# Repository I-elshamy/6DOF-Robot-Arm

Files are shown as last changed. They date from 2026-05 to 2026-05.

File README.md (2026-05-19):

# 🤖 Industrial Robotics Project

Welcome to our Industrial Robotics project repository!  
This project was developed as part of the Industrial Robotics course submission and focuses on building, controlling, and simulating a robotic arm system using modern robotics tools and embedded systems.

---

<table>
<tr>
<td>

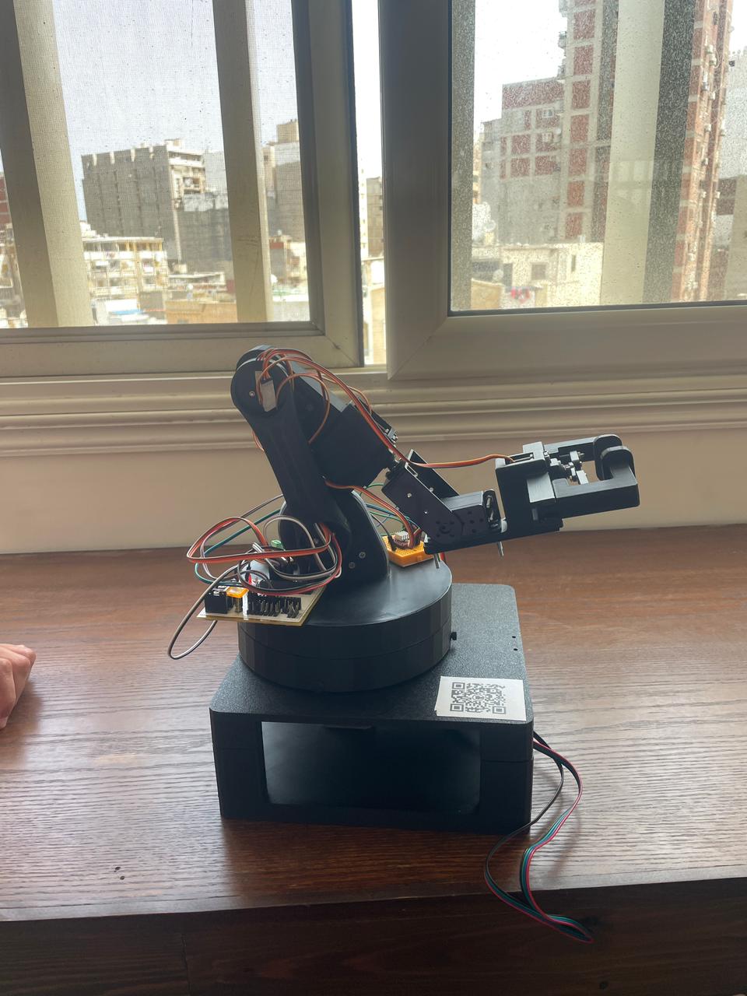
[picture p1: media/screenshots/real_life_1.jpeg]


</td>
<td>

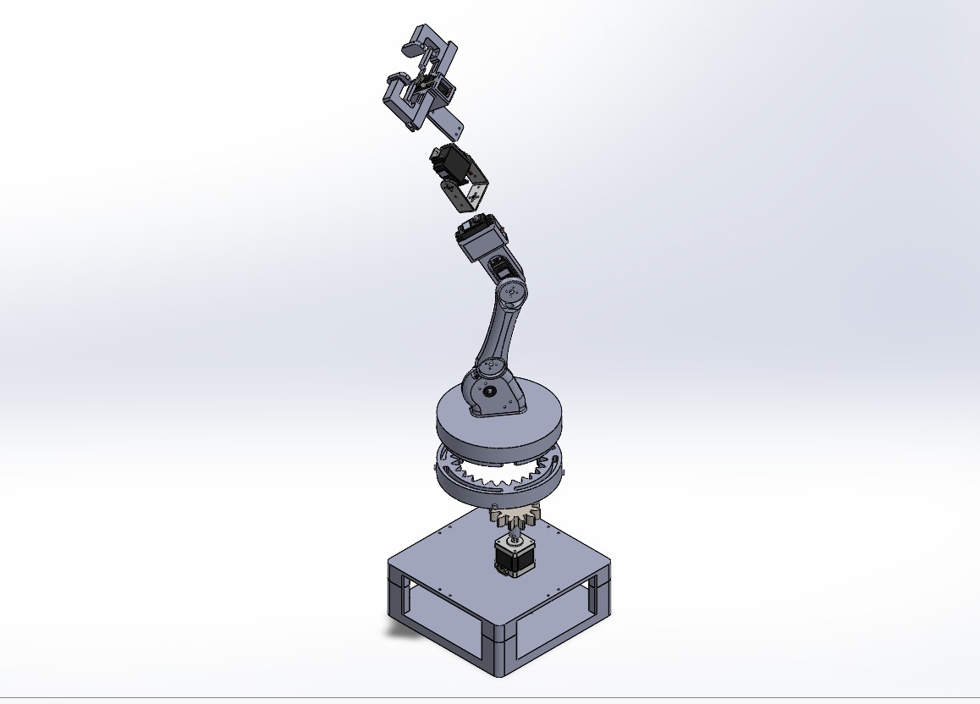
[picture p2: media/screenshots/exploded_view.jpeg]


</td>
</tr>
</table>

---

## 🚀 Project Overview

The project combines:

- 🦾 Robotic arm design and control
- ⚙️ ROS 2 integration
- 🎮 Motion planning with MoveIt
- 🔌 Arduino/ESP32 communication
- 🖥️ Simulation and visualization
- 📡 Serial/UART communication

The goal is to create a smart and flexible robotic manipulation system capable of performing automated movements and task execution.

---

## 🛠️ Technologies Used

- ROS 2
- MoveIt 2
- Gazebo
- RViz
- Arduino / ESP32
- Python
- C++
- UART Serial Communication
- MATLAB / Simulink
- micro-ROS
- SolidWorks

---

## 📂 Repository Structure

```text
src/
 ├── robot_description/
 ├── robot_control/
 ├── moveit_config/
 ├── serial_communication/
 └── simulation/

firmware/
cad/
stl/
matlab/
pcb/
media/
docs/
```

# Full Stack Robotic Arm System

A complete full-stack robotic arm platform integrating mechanical design, simulation, motion planning, embedded control, and real hardware execution using ROS 2, MoveIt 2, Gazebo, ESP32, MATLAB/Simulink, Arduino, and SolidWorks.

---

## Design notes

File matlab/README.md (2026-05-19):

# 🦾 Robotic Arm — MATLAB Simscape Model

A full robotic arm simulation built with MATLAB & Simscape Multibody, covering kinematics, trajectory planning, and servo control.

---

## 📁 Project Structure

```
assembly/
├── Assem2.slx                        # Main Simscape Multibody model
├── Assem2_DataFile.m                 # Auto-generated model data (rigid transforms, parameters)
├── rigidtree.m                       # Imports robot model & builds rigid body tree
│
├── Assem2_fkin.slx                   # Forward kinematics simulation
├── Assem2_inversekin.slx             # Inverse kinematics simulation
├── Assem2_jacobian.slx               # Jacobian matrix computation
│
├── Assem2_trajectoryplanning.slx     # Trajectory planning (end-effector path)
├── Assem2_trajectoryangles.slx       # Trajectory planning (joint angles output)
│
├── Assem2_p2p.slx                    # Point-to-point motion test
├── Assem2_p2pangles.slx              # Point-to-point motion (joint angles output)
│
├── trajec.m                          # Trajectory waypoints, matrices & shared workspace data
├── servo_control.slx                 # Servo control — manual slider interface
└── trajectory_servo_control.slx      # Servo control — runs angles from trajec.m
```

---

## ▶️ How to Run

> **Order matters.** Always follow the steps below — skipping a step will cause errors.

### Step 1 — Initialize the Model Data

Run `Assem2_DataFile.m` **first**, every time you open a new MATLAB session. This loads all rigid body transform data (translations, rotations, joint IDs) required by the Simscape model.

```matlab
run('Assem2_DataFile.m')
```

> This file is auto-generated by Simscape Multibody Import and should **not** be manually edited beyond numerical values.

---

### Step 2 — Build the Rigid Body Tree

Before running any kinematics or Jacobian scripts, run `rigidtree.m` to import the robot and construct its rigid body tree representation.

```matlab
[dof, ArmInfo] = importrobot('Assem2.slx')
% or simply:
run('rigidtree.m')
```

This gives you:
- `dof` — degrees of freedom of the robot
- `ArmInfo` — full rigid body tree used in all downstream computations

---

### Step 3A — Kinematics & Jacobian

Once Step 1 and Step 2 are complete, you can open and run any of the following Simulink models independently:

| File | Description |
|---|---|
| `Assem2_fkin.slx` | Computes end-effector pose from joint angles |
| `Assem2_inversekin.slx` | Solves joint angles for a target end-effector pose |
| `Assem2_jacobian.slx` | Computes the Jacobian matrix at a given configuration |

---

### Step 3B — Trajectory Planning & Servo Control

For trajectory planning or servo control, an **additional setup step** is required. Run `trajec.m` first to load the waypoints, transformation matrices, and shared variables needed by these models.

```matlab
run('trajec.m')
```

Then open and simulate any of the following:

| File | Description |
|---|---|
| `Assem2_trajectoryplanning.slx` | Trajectory planning — end-effector Cartesian path |
| `Assem2_trajectoryangles.slx` | Trajectory planning — joint angles output |
| `Assem2_p2p.slx` | Point-to-point motion test |
| `Assem2_p2pangles.slx` | Point-to-point motion — joint angles output |
| `trajectory_servo_control.slx` | Servo control driven by angles from `trajec.m` |

The `servo_control.slx` model does **not** require `trajec.m` — it uses built-in sliders for manual joint control:

| File | Description |
|---|---|
| `servo_control.slx` | Manual servo control via interactive sliders |

---

## 🔁 Full Run Order Summary

```
1. Assem2_DataFile.m                    ← Always first
2. rigidtree.m                          ← Required for all models below
   ├── Assem2_fkin.slx
   ├── Assem2_inversekin.slx
   ├── Assem2_jacobian.slx
   └── servo_control.slx               ← Manual sliders, no trajec.m needed

   + trajec.m                          ← Also required for trajectory & automated control
      ├── Assem2_trajectoryplanning.slx
      ├── Assem2_trajectoryangles.slx
      ├── Assem2_p2p.slx
      ├── Assem2_p2pangles.slx
      └── trajectory_servo_control.slx
```

---

## 🎥 Demo

A video demonstration of the trajectory planning simulation is included below.

> 📽️ `trajectory_demo.mp4` — End-effector following a planned path through a sequence of waypoints.

---

## 🛠️ Requirements

- MATLAB R2024a or later
- Simscape Multibody Toolbox
- Robotics System Toolbox (for `rigidBodyTree`, `inverseKinematics`)

---

## 📌 Notes

- Do **not** edit the physical units in `Assem2_DataFile.m` comments — only numerical values may be changed.
- Do **not** add arbitrary code to `Assem2_DataFile.m`.
- All scripts assume the current MATLAB working directory is set to the `assembly/` folder.

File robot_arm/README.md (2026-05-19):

# ROS2 Workspace (MoveIt 2 + Gazebo + ESP32 Control Stack)

This workspace contains the complete ROS 2 control pipeline for the robotic arm project, including:

- Robot visualization using RViz
- Motion planning using MoveIt 2
- Physics simulation using Gazebo
- Real hardware communication using micro-ROS and ESP32
- Joystick-based gripper control
- Joint state to servo angle conversion

The stack was initially generated using **MoveIt Setup Assistant** and later extended with custom launch files and control nodes for hardware integration.

---

# System Pipeline

```text
MoveIt 2
    │
    v
ROS 2 Controllers
    │
    v
/joint_states
    │
    v
control_micro node
    │
    v
micro-ROS Agent
    │
    v
ESP32
    │
    v
Servo Motors / Gripper
```

---

# Workspace Features

- Full MoveIt 2 integration
- Gazebo simulation support
- RViz visualization
- ESP32 hardware communication
- micro-ROS WiFi bridge
- Real-time joint state conversion
- Servo angle mapping
- Joystick gripper control
- Parallel simulation + hardware testing

---

# ROS2 Packages

| Package | Description |
|---|---|
| `arm_description` | URDF/Xacro robot model + launch files |
| `arm_moveit_config` | MoveIt Setup Assistant generated package |
| `arm_control` | Joint state to servo conversion node |
| `micro_ros_interface` | ESP32 communication layer |
| `gazebo_simulation` | Gazebo simulation integration |

---

# Running the Project

## 1. Launch RViz and Verify Robot URDF

```bash
# Launch RViz and visualize robot model
ros2 launch arm_description display.launch.py
```

### RViz Screenshot

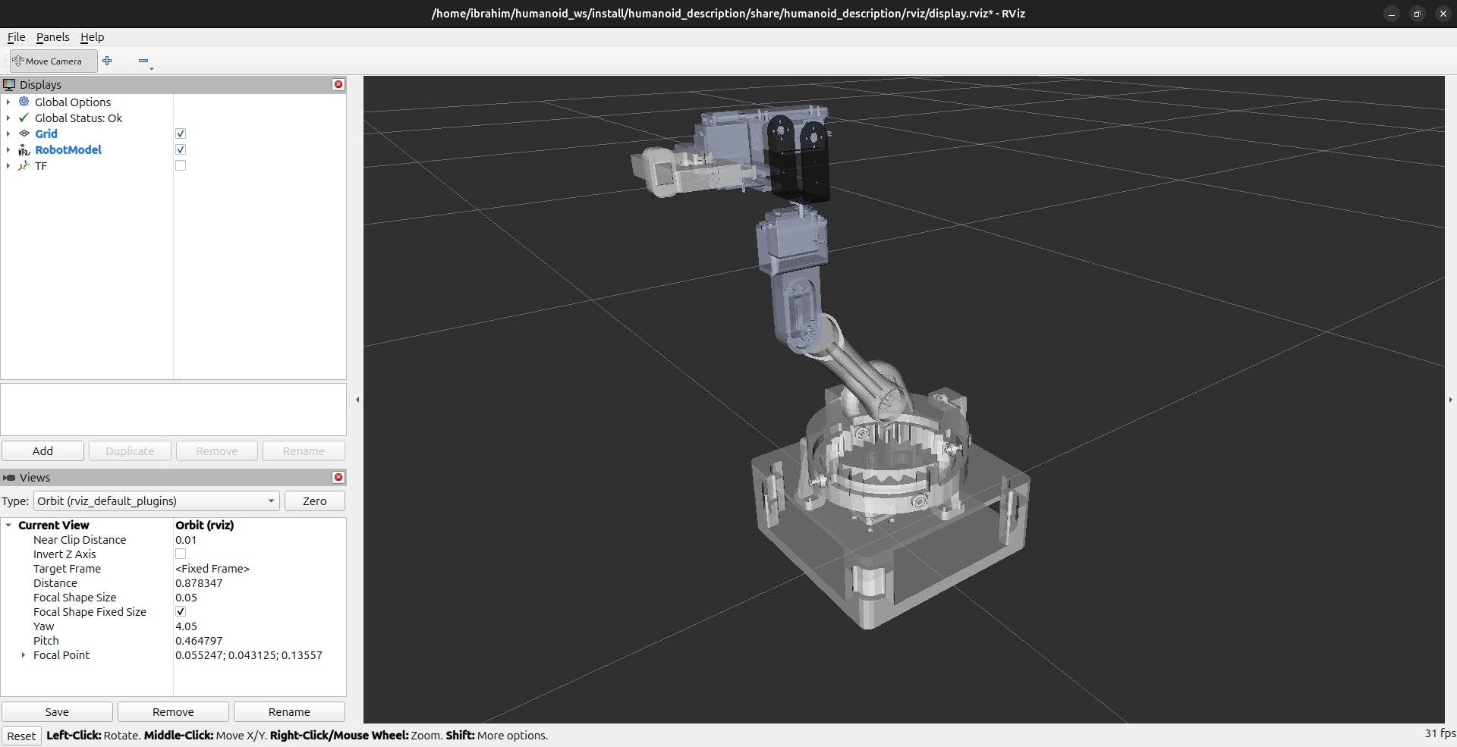
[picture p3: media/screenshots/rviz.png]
RViz


### RViz Demo

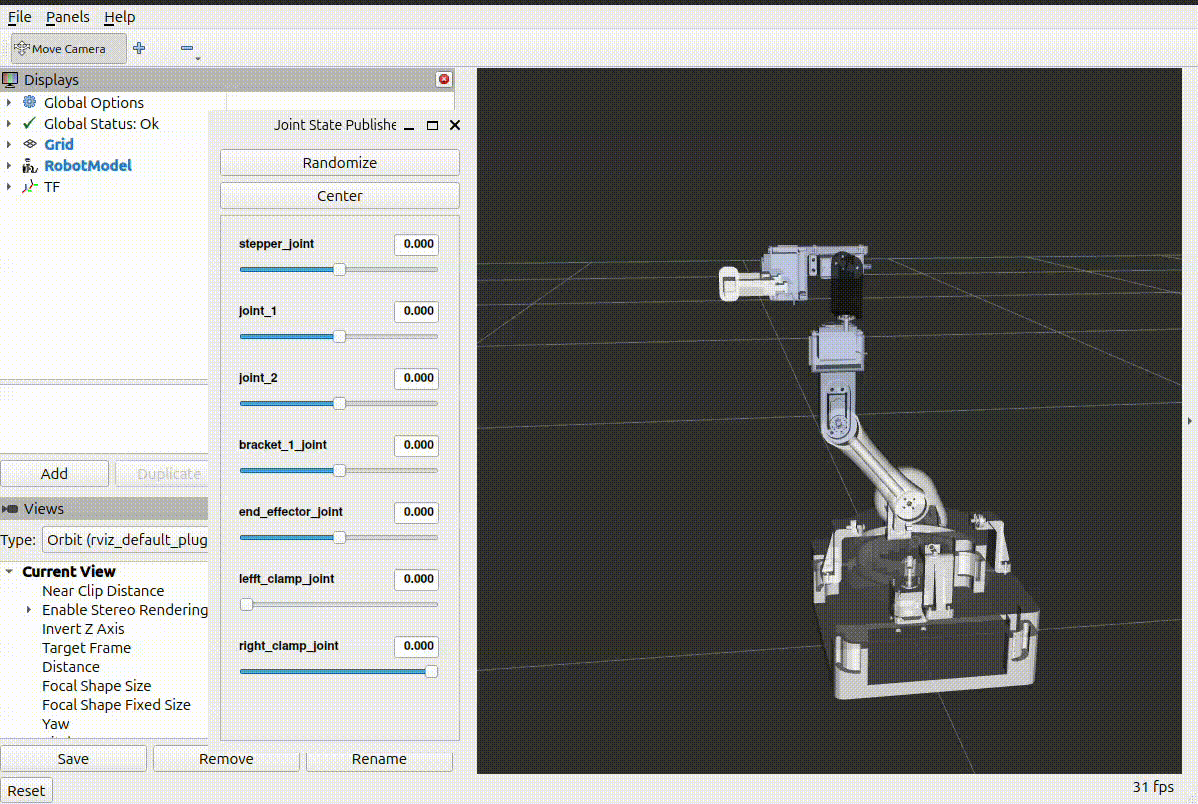
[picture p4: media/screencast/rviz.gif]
RViz Demo


---

## 2. Launch Gazebo + MoveIt 2 Simulation

```bash
# Launch Gazebo simulation + MoveIt motion planning
ros2 launch arm_description moveit_gazebo.launch.py
```

### Gazebo Screenshot

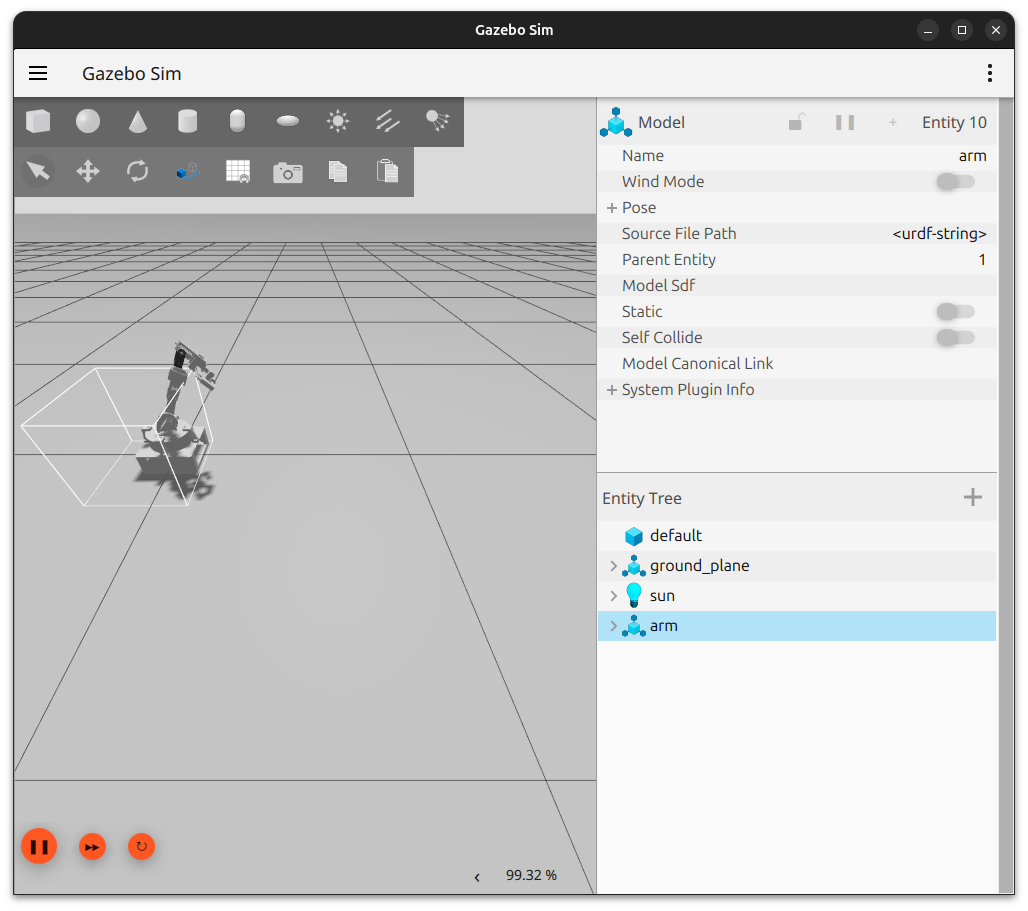
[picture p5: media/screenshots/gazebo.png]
Gazebo


### MoveIt Screenshot

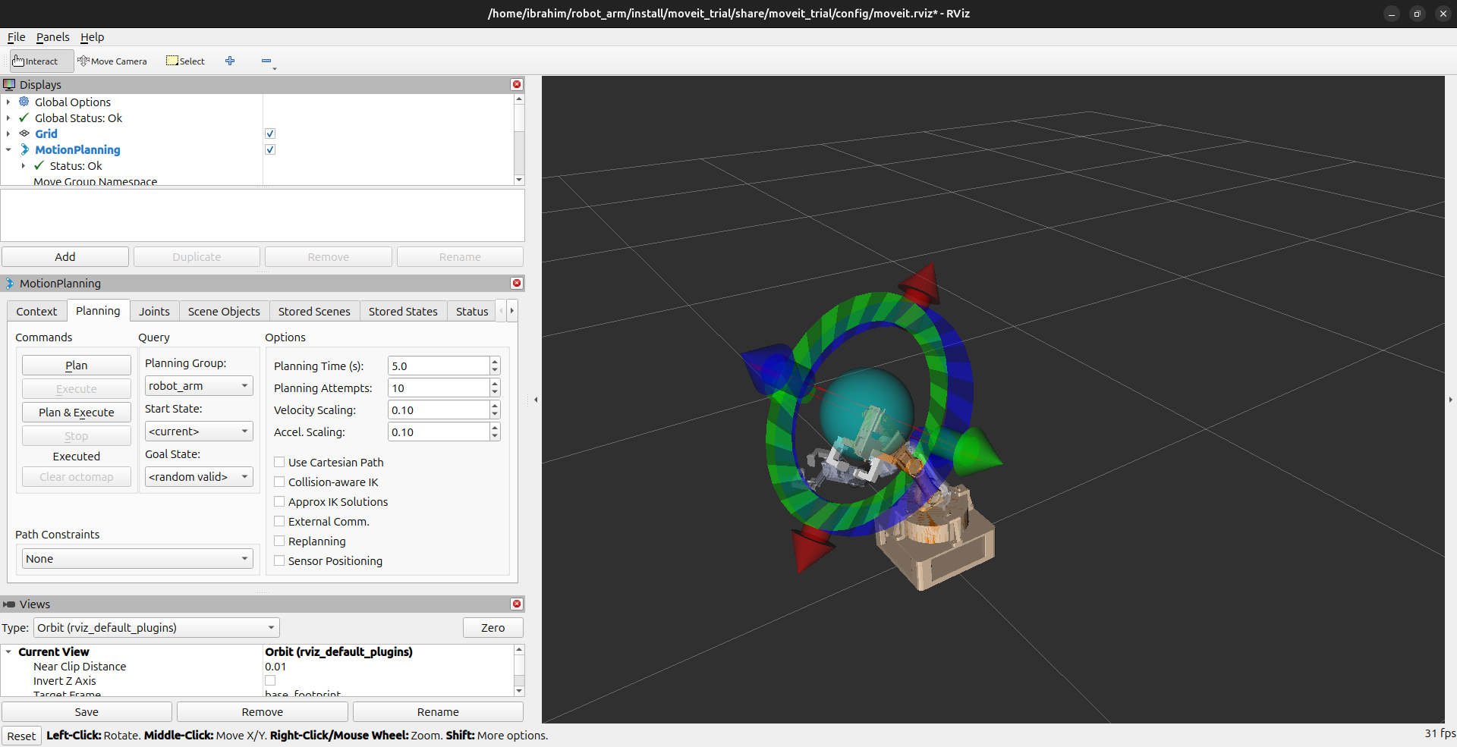
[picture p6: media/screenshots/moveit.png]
MoveIt


### MoveIt Demo

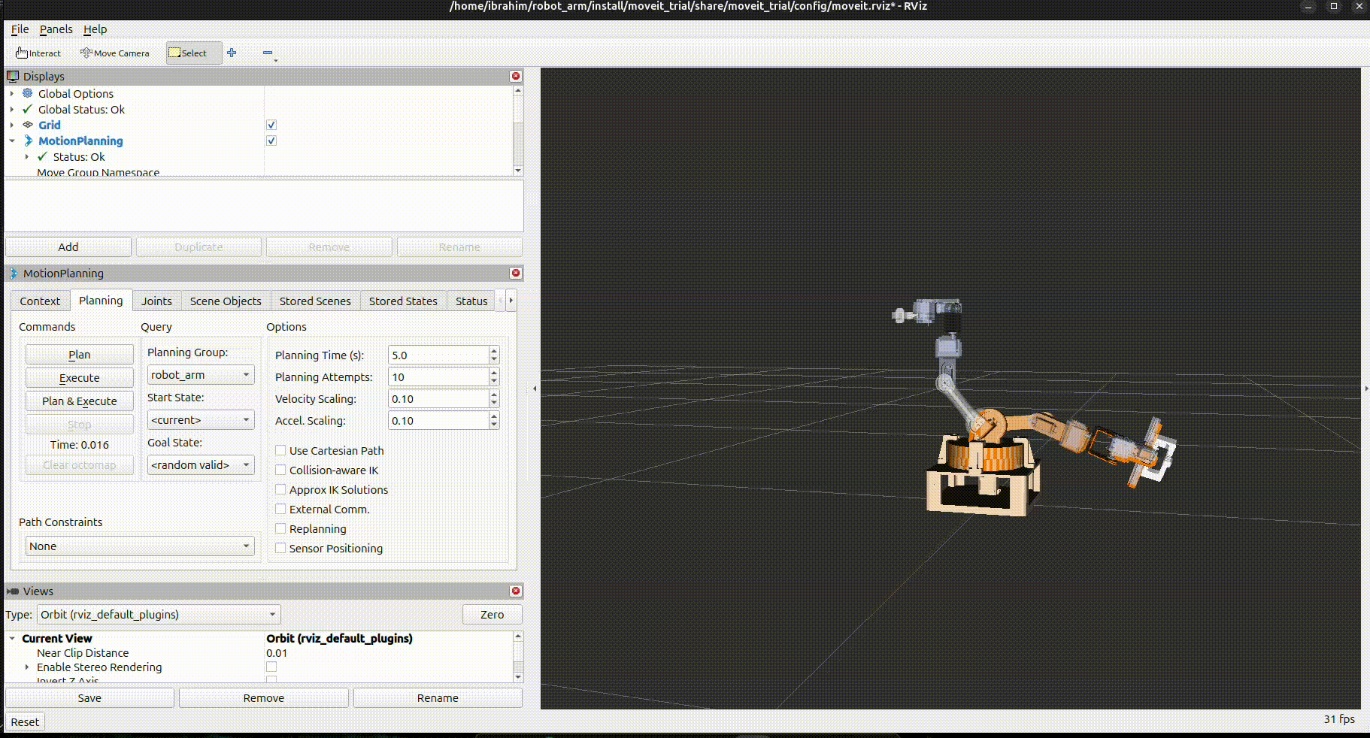
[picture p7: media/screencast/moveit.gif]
MoveIt Demo


### Gazebo Mimicking MoveIt Motion

Gazebo Demo

---

## 3. Run Joint State → Servo Control Node

```bash
# Convert joint states into servo angles for ESP32
ros2 run arm-control control_micro
```

This node:
- Subscribes to `/joint_states`
- Converts joint angles into servo-compatible commands
- Publishes processed angles for ESP32 execution

---

## 4. Launch Joystick Control

```bash
# Launch joystick node for gripper control
ros2 run joy joy_node
```

This node allows:
- Manual gripper opening/closing
- Real-time joystick interaction

---

## 5. Run micro-ROS Agent (WiFi Mode)

```bash
# Start micro-ROS UDP bridge
ros2 run micro_ros_agent micro_ros_agent udp4 --port 8888
```

This creates the communication bridge between:
- ROS 2 host machine
- ESP32 micro-ROS client firmware

---

# ESP32 Firmware Configuration

Before running WiFi mode, edit the firmware located at:

```text
firmware/robot_arm_trial2/
```

Update the network parameters inside the setup function for micro-ROS transports.

Example:

```cpp
const char* ssid = "YOUR_WIFI_NAME";
const char* password = "YOUR_WIFI_PASSWORD";
IPAddress agent_ip(192,168,1,100);
```

---

# Recommended Startup Order

```text
1. Start micro-ROS agent
2. Launch RViz (optional URDF verification)
3. Launch Gazebo + MoveIt
4. Run control_micro node
5. Launch joystick node (optional)
```

---

# Topics

## Input Topics

| Topic | Type | Description |
|---|---|---|
| `/joint_states` | `sensor_msgs/JointState` | Joint positions from controllers |

---

## Output Topics

| Topic | Type | Description |
|---|---|---|
| `/servo_angles` | Custom / std_msgs | Servo commands sent to ESP32 |

---

# Dependencies

- ROS 2 Jazzy / Humble
- MoveIt 2
- Gazebo
- RViz
- micro-ROS
- `joy` package
- Python3 / `rclpy`

---

# Notes

- MoveIt Setup Assistant was used for initial robot configuration
- Gazebo and MoveIt are launched together through a custom launch file
- ESP32 receives commands over WiFi using UDP micro-ROS
- System supports both simulation and real hardware execution
- Servo mapping depends on physical calibration

---

# Future Improvements

- Encoder feedback integration
- Closed-loop control
- Force/torque sensing
- Trajectory smoothing
- Computer vision integration
- Autonomous pick-and-place pipeline

---

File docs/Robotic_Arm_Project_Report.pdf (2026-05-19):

## Industrial Robotics 6-DOF Robotic Arm — Design, Simulation, and Implementation

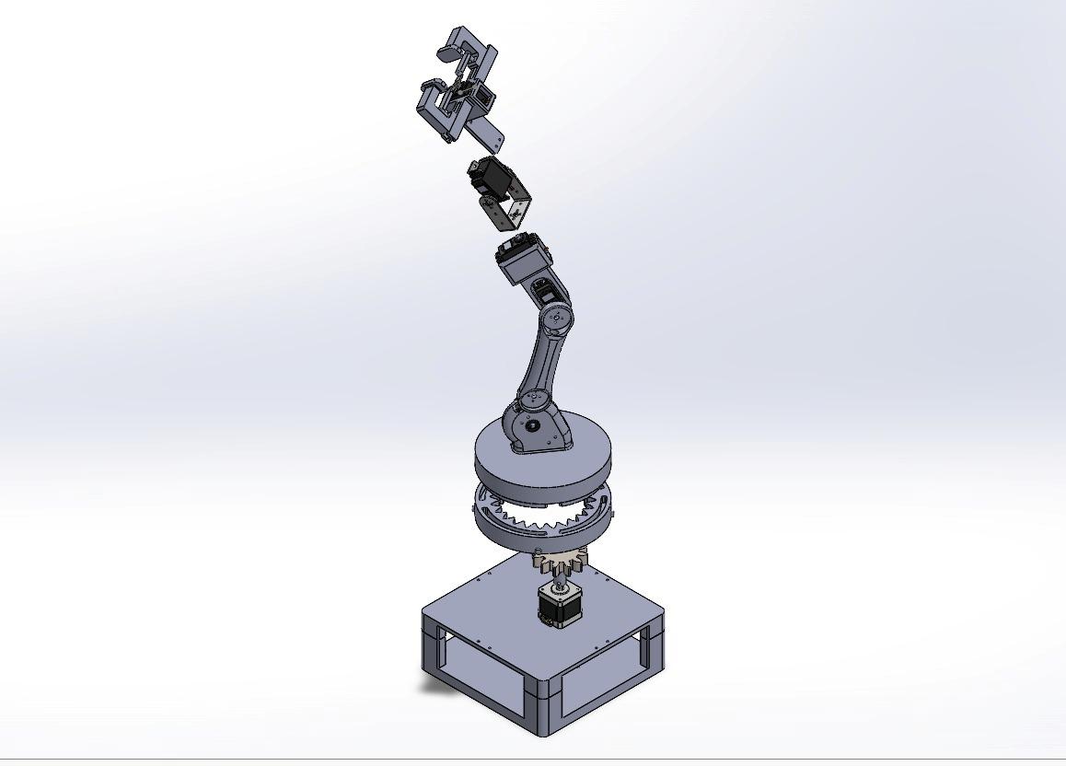
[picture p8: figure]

## Prepared by:

- Ibrahim Elshami | 8819
- Phoebe Emile | 9116
- Youssef Fawzy | 8680
- Yehia Zahran | 8765
- Maya Osama | 8582
- Karim Heiba | 8929
- Serag Elgewily | 8795

## 1. Mechanical Design (SolidWorks)

### 1. Kinematic Configuration

The arm follows a classic articulated 6R configuration. The shoulder, elbow, and wrist axes were arranged so that the last three joint axes intersect at a single point, producing a spherical wrist. This choice simplifies the inverse-kinematics decoupling between position and orientation.

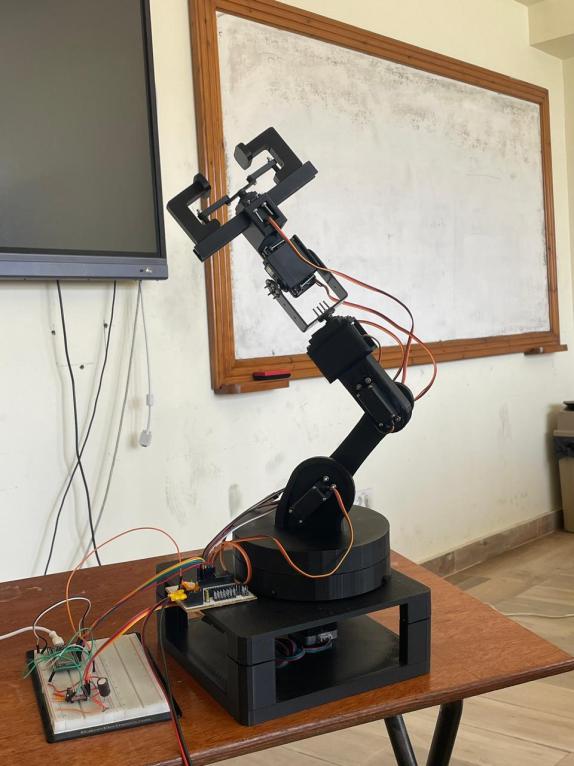
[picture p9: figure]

Figure 1: Photo of the arm

### 2. Base — Internal Gear Driven by Stepper

The base is the most heavily loaded joint, since it carries the entire arm and any payload moment. To obtain a high reduction ratio with low backlash and a compact footprint, the base uses an internal (ring) gear fixed to the rotating platform, meshed with a pinion mounted on the steppermotor shaft. The stepper drives the pinion, the pinion walks around the internal teeth, and the platform rotates relative to the fixed base. Vertical guides were mounted on the base to ensure the stability of the gear-cap assembly in case of larger payload. Guides were equipped with rolling bearings too for smooth movement without friction with the cap surface.

- Stepper motor model: Nema 17
- Pinion / ring teeth: 10 : 20 teeth
- Resulting gear ratio: 2:1 — providing fine angular resolution at the base.
However, after printing and assembling the parts, some challenges were encountered regarding the relative motion between the gears. This has lead to removing the pinion driving gear and fixing the stepper shaft directly to the cap-ring assembly.

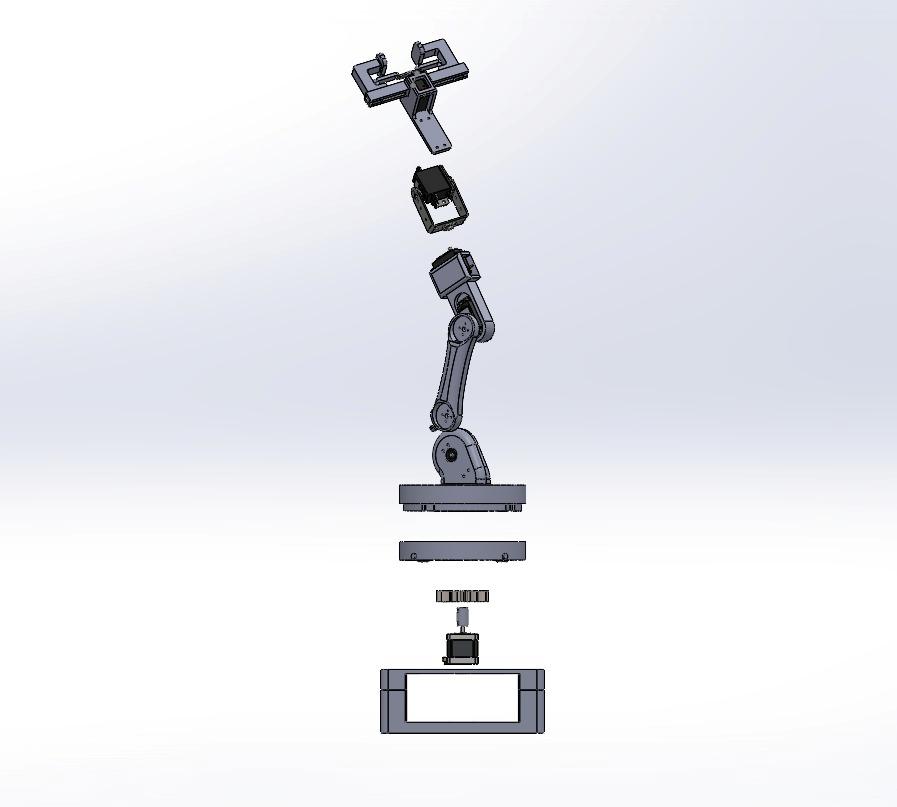
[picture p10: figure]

Figure 2: Exploded view

### 3. Links, Joints, and Servo Actuation

Joints J2 through J6 are actuated by servo motors (mg945) mounted directly at or near the corresponding axis. Each servo is housed in a custom bracket designed in SolidWorks to align its output shaft with the joint axis and to react bending loads onto the mating link rather than the servo body.

All parts, including the upper and lower base and the gears, were 3D printed in black PLA+ filament. Only 2 metal brackets were used to provide the rotation of the end effector around the z-axis. Parts with higher loads, such as the pinion, were printed with higher infill density to ensure they endure the required strength.

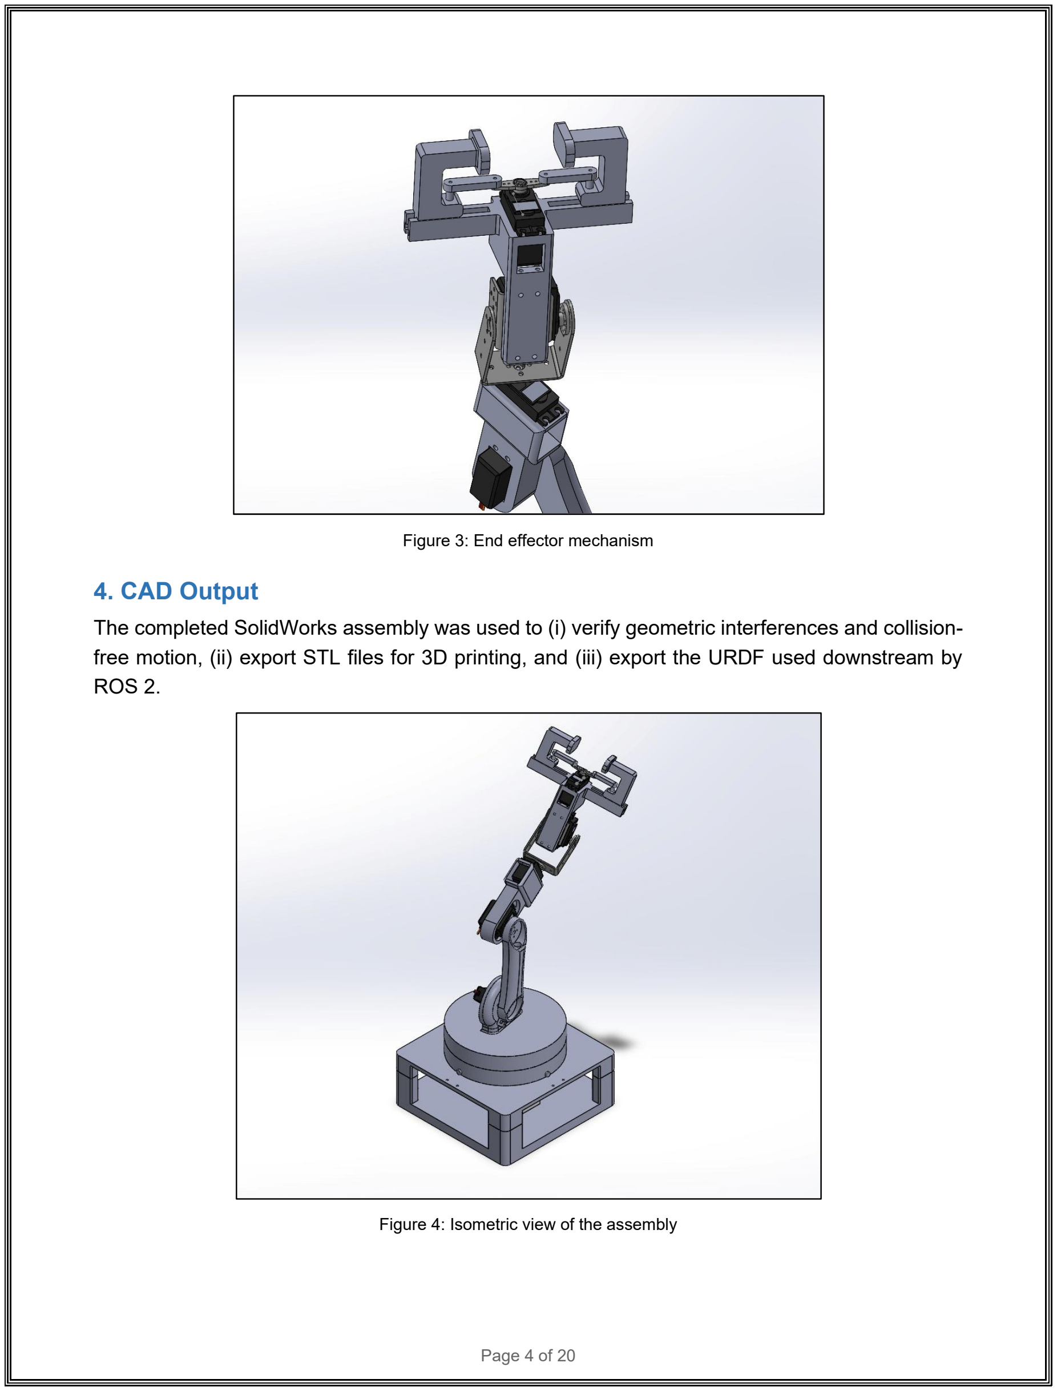
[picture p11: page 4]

Figure 3: End effector mechanism

### 4. CAD Output

The completed SolidWorks assembly was used to (i) verify geometric interferences and collisionfree motion, (ii) export STL files for 3D printing, and (iii) export the URDF used downstream by ROS 2.

Figure 4: Isometric view of the assembly

## 2. Simulation in Simscape Multibody

The SolidWorks assembly was first simplified by removing the upper, lower base and the guides to minimize the number of blocks in the Simscape Multibody and only import the effective parts of the assembly to ensure smooth and efficient simulation. The assembly was then imported into MATLAB / Simulink Simscape Multibody using the Simscape Multibody Link exporter. This produced a hierarchical multibody model in which each link is a rigid body and each joint is a Revolute Joint block with its actuation and sensing ports exposed.

### 1. Model Setup

- The coordinate frames of the robot base and each link of the arm were initially identified in the SolidWorks assembly to match the world frame of the mechanics explorer on Simscape.
- Each revolute joint was configured to be actuated by received motion and outputs a signal that represents its position. Signals are then linked to PS-simulink converter to use them later in the kinematics analysis.
- Inertial properties (mass, center of mass, inertia tensor) were inherited from SolidWorks material assignments and saved in the Assem2_DataFile.m

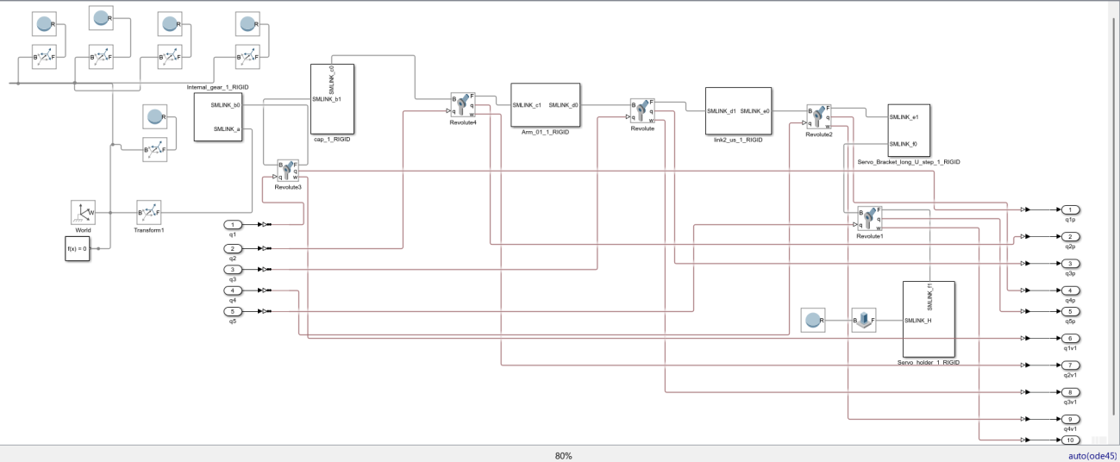
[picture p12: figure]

Figure 5: Simscape block diagram

Spheres added relatively to the world frame will be later used for the trajectory planning.

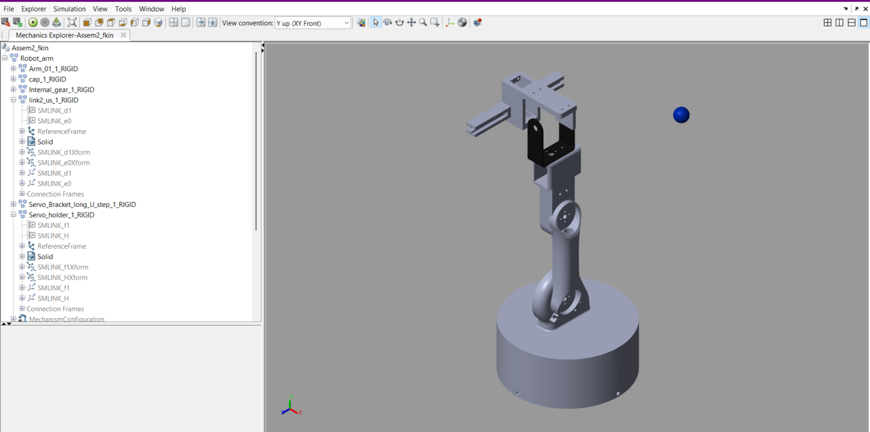
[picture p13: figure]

Figure 6: Mechanics explorer view

### 2. Forward Kinematics

Forward kinematics was implemented by feeding the 5 joint angles into the Revolute Joint blocks through the whole assembly block as shown in the figure and reading the corresponding position of each joint then converting it into a homogeneous transformation with the “Get transform” block. This produced the end-effector position (x, y, z) and orientation (as a rotation matrix and ZYX Euler angles) for any input joint configuration.

The revolute joint controlling the end effector was not implemented in this step just for simplification. The gripper motion could be controlled independently later.

It is noticed that the translation column vector is the same as the resulting end-effector position. The gain blocks were used to convert from radian to degree and vice versa.

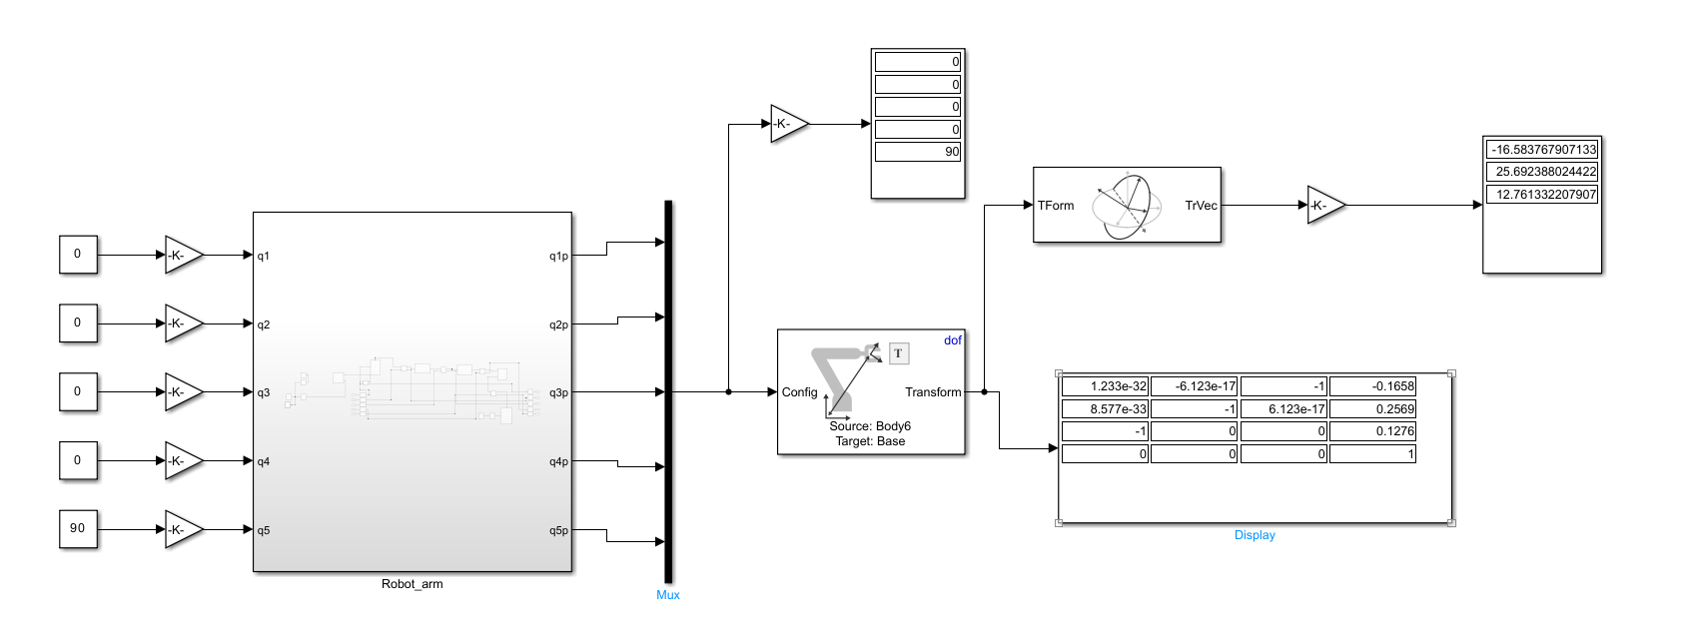
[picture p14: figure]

Figure 7: Forward kinematics block diagram

The Denavit–Hartenberg (DH) parameters extracted from the CAD model are summarized below and were used as the reference for all analytical cross-checks.

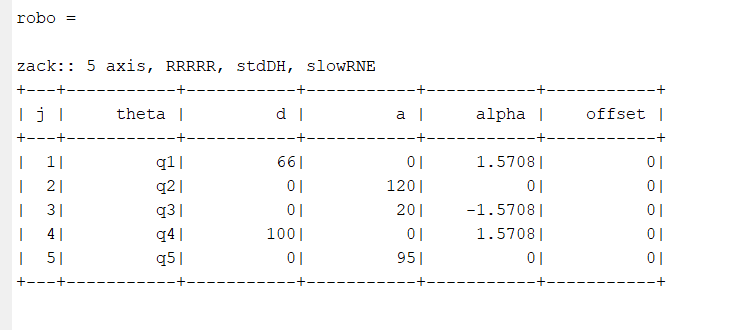
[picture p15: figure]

Figure 8: DH table

### 3. Inverse Kinematics

Inverse kinematics was solved using the “Inverse kinematics” block that receive the required end effector position after converting it into a 4×4 homogeneous matrix and initial guesses for the angles. The angles are then computed and sent to the revolute joints. It is noticed that these angles are matching exactly those read from the outputs of the joints.

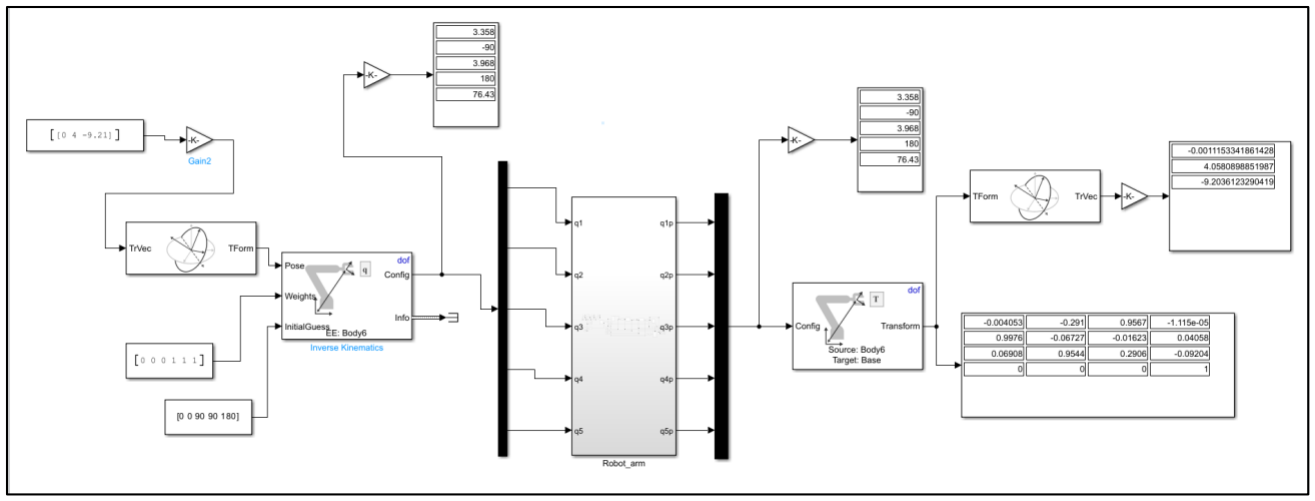
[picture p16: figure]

Figure 9: Inverse kinematics block diagram

### 4. Jacobian Analysis

The Jacobian matrix was simply computed with the “Get Jacobian” block that only needs the angles resulting from the inverse kinematics as input to calculate the 6×6 matrix.

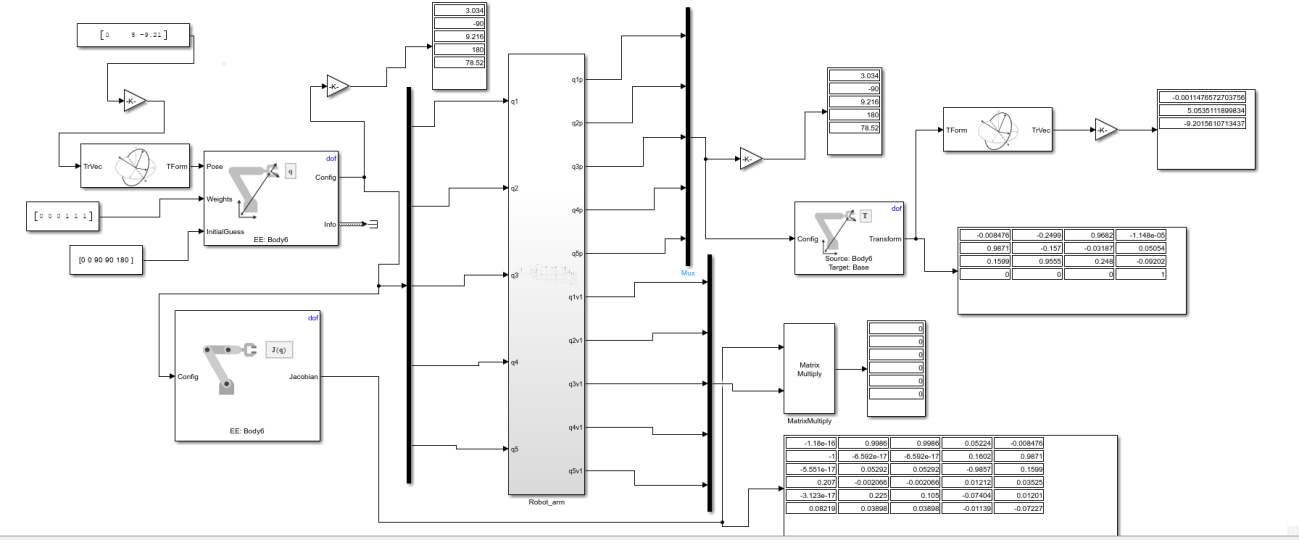
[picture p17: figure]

Figure 10: Jacobian analysis block diagram

### 5. Trajectory Planning

The cubic polynomial trajectory planning method was used to control the arm to move in a path that draws nearly a square. However, this was implemented with 2 different approaches:

- Using Positions: a matrix of the required end-effector position was fed to “Polynomial trajectory” block and the output was then sent to the inverse kinematics algorithm to compute the angles.
- Using angles: the angles of each revolute joint were fed to the block and the output is sent directly to the joints.

Both generated trajectories were played back through the Simscape model to confirm smooth motion, absence of joint-limit violations, and respect of velocity limits.

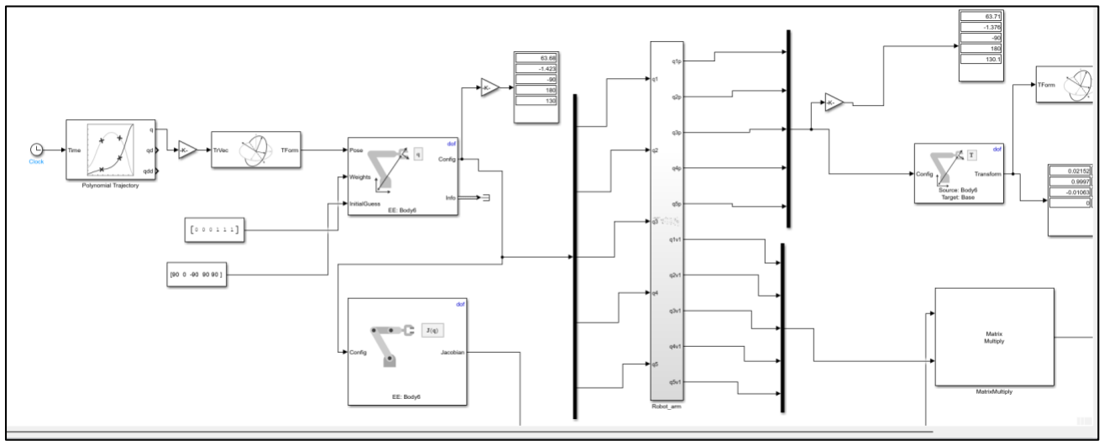
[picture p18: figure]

Figure 11: Trajectory planning using positions

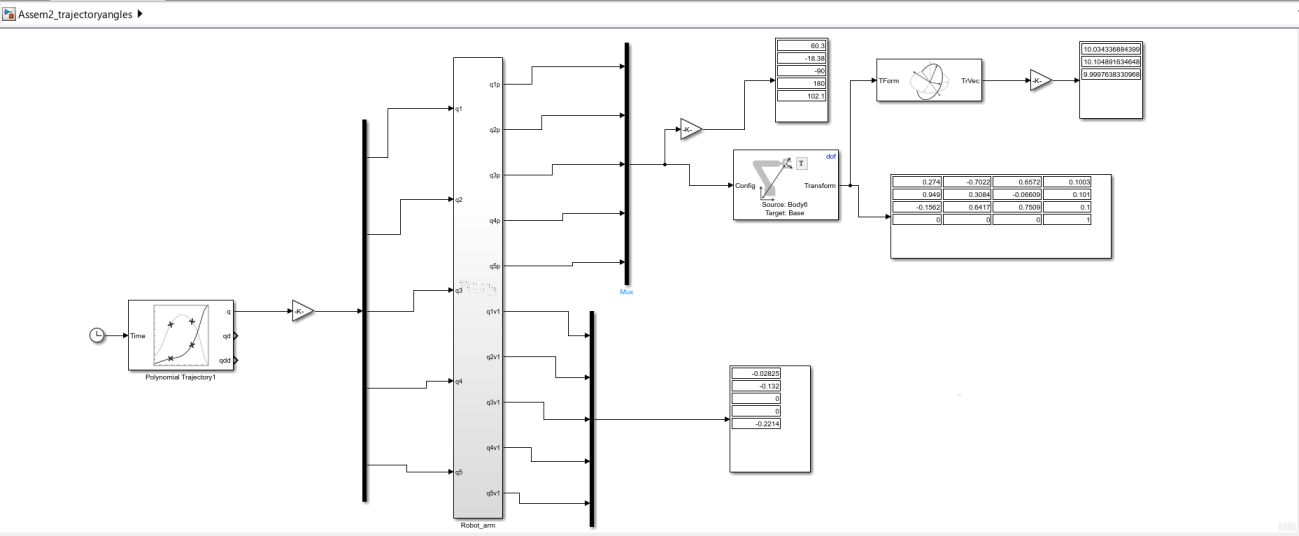
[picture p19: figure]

Figure 12: Trajectory planning using angles

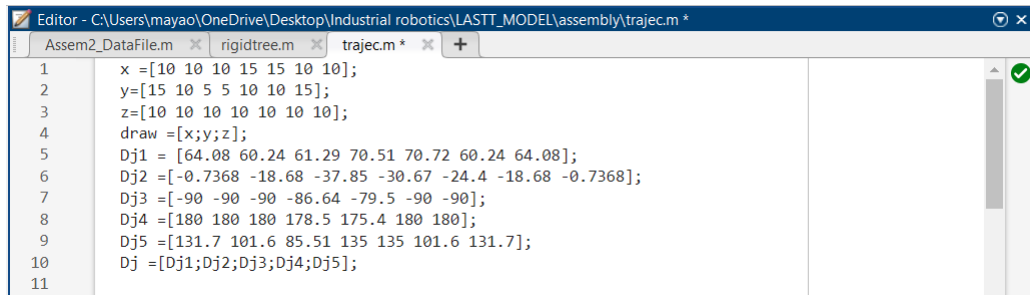
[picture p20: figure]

Figure 13: Positions and angles matrices

### 6. ESP32 deployment on MATLAB:

To publish the generated path to the microcontroller, an add-on hardware package has been installed to establish a connection between the ESP32 and the Simulink model. Blocks called “Servo wiring” are implemented in the model representing each servo with its respective pin on the ESP32. These blocks are fed with a repeating sequence representing the matrices of the angles resulting from the inverse kinematics after adding a constant angle value unique to each one.

The addition of constant angle values is interpreted by compensating the difference between the zero position of each servo in real life and the simulation. Moreover, the limits of the servo angles on MATLAB are ranging from -90 to 90, while the actual limits are from 0 to 180 degrees.

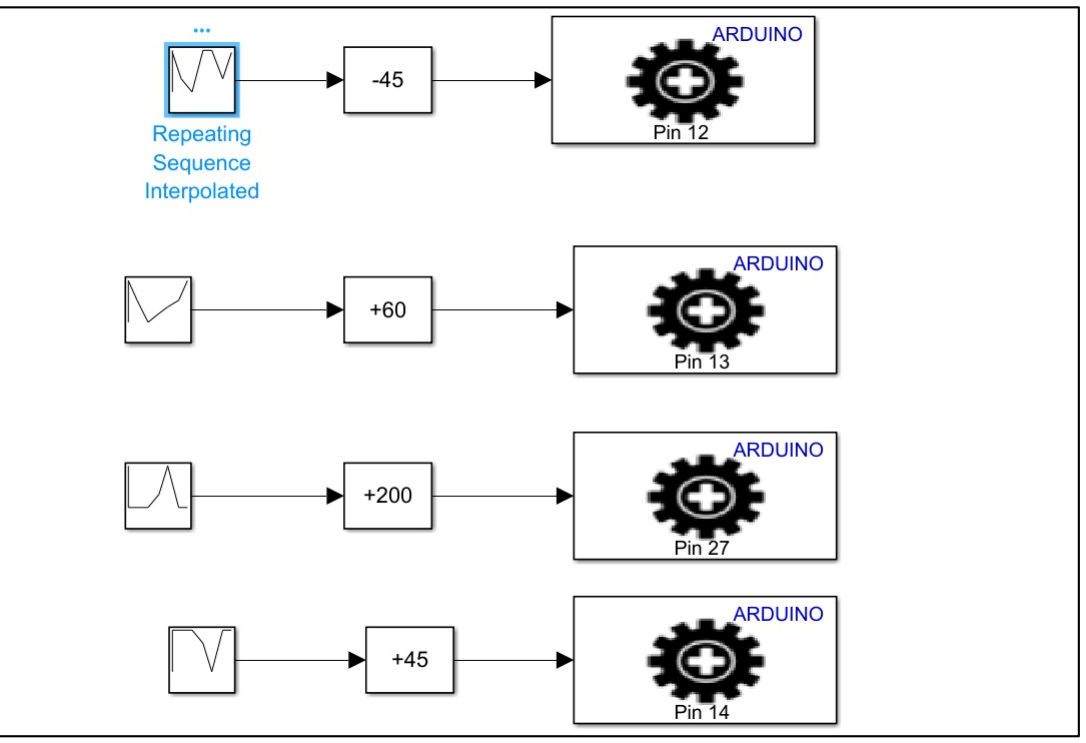
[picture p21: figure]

Figure 14: ESP32 control block diagram

## 3. Kinematics with the Peter Corke Toolbox

To independently validate the Simscape kinematic model, a parallel implementation was written in both Matlab and Python using the Peter Corke Robotics Toolbox (roboticstoolbox-py). The same DH table from Section 2.2 was used to build a SerialLink / DHRobot model of the manipulator.

### 1. Implementation

- Built a DHRobot object from the modified-DH table of the arm.
- Forward kinematics: computed using robot.fkine(q) and compared element-wise with the Simscape Transform Sensor output.
- Inverse kinematics: computed using both the closed-form geometric solution and the iterative numerical solver (robot.ikine_LM) provided by the toolbox.
- Visualization: the toolbox’s built-in 3D plot was used to verify joint configurations and trajectories visually.

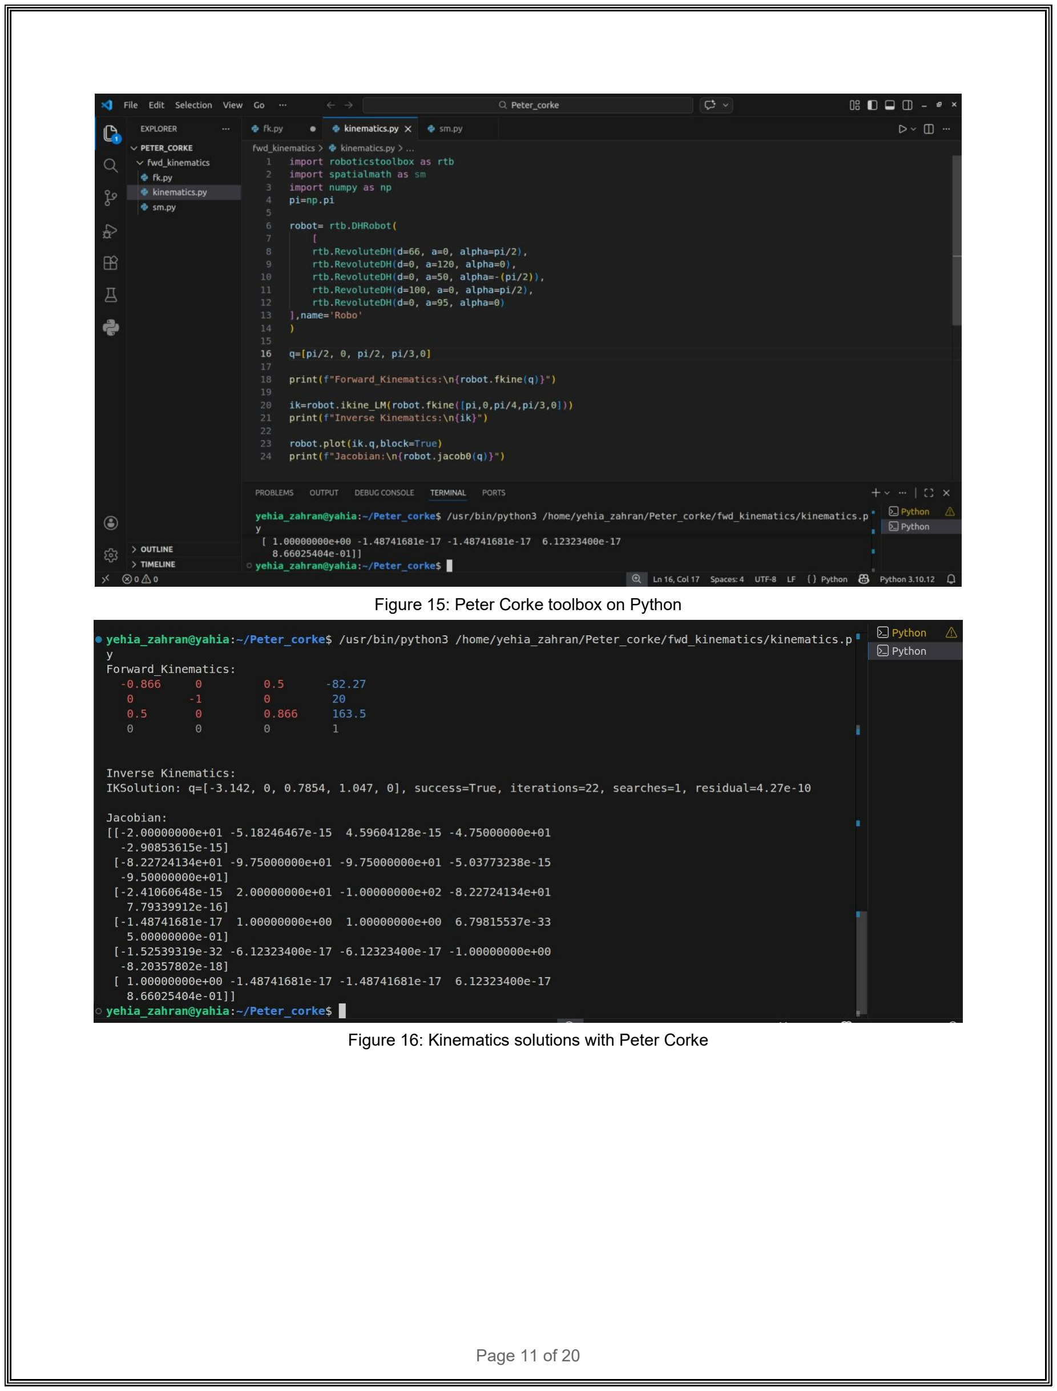
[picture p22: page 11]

Figure 15: Peter Corke toolbox on Python

Figure 16: Kinematics solutions with Peter Corke

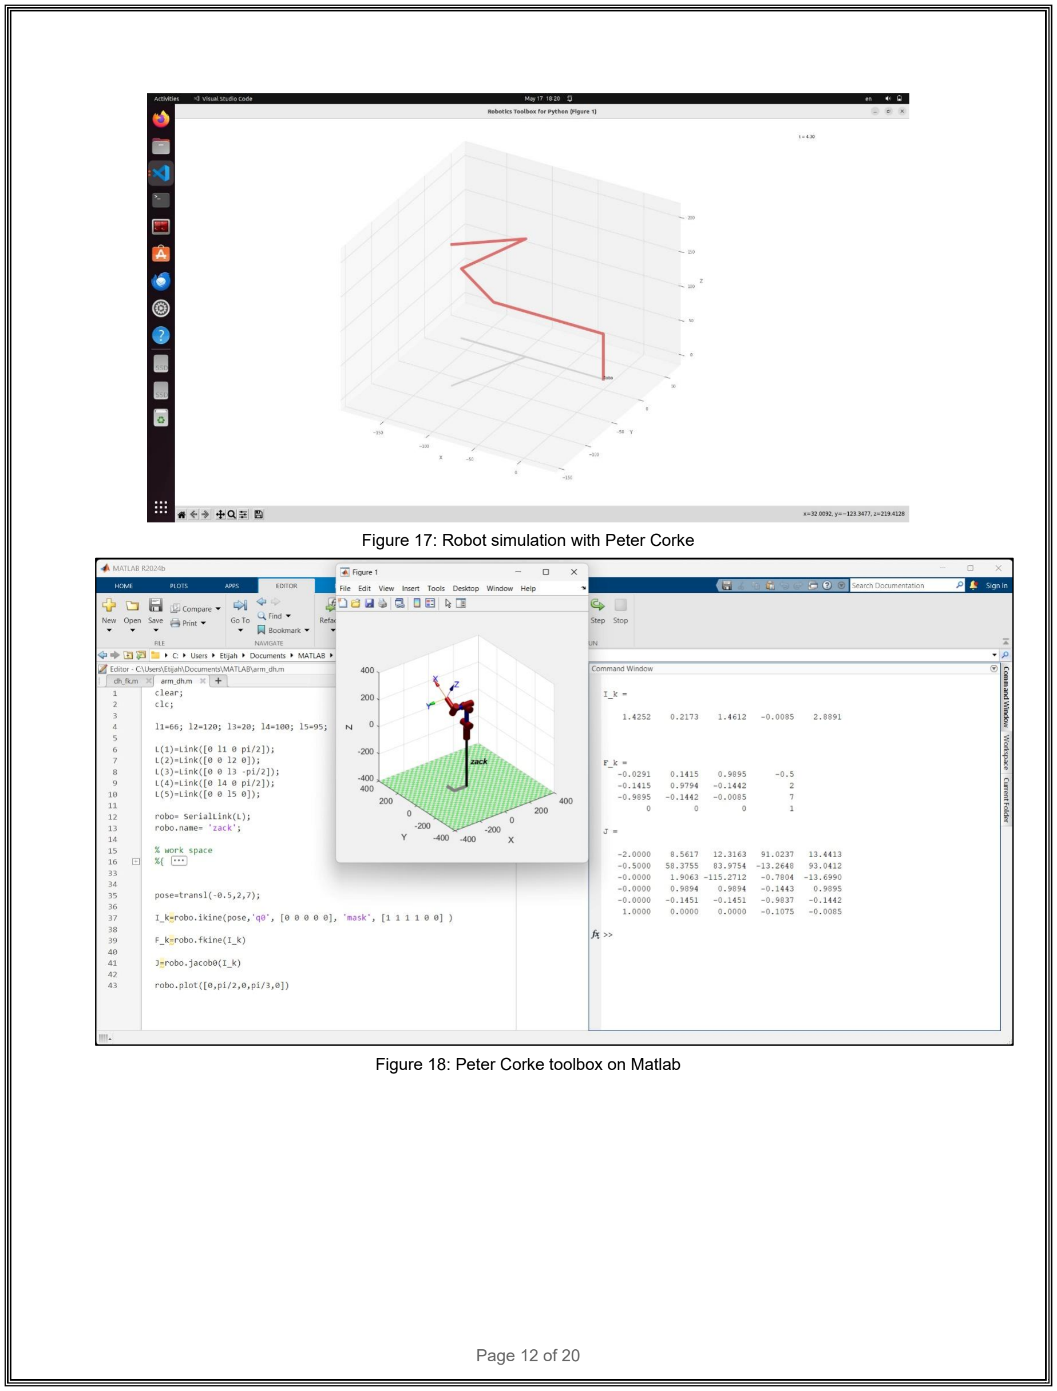
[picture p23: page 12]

Figure 17: Robot simulation with Peter Corke

Figure 18: Peter Corke toolbox on Matlab

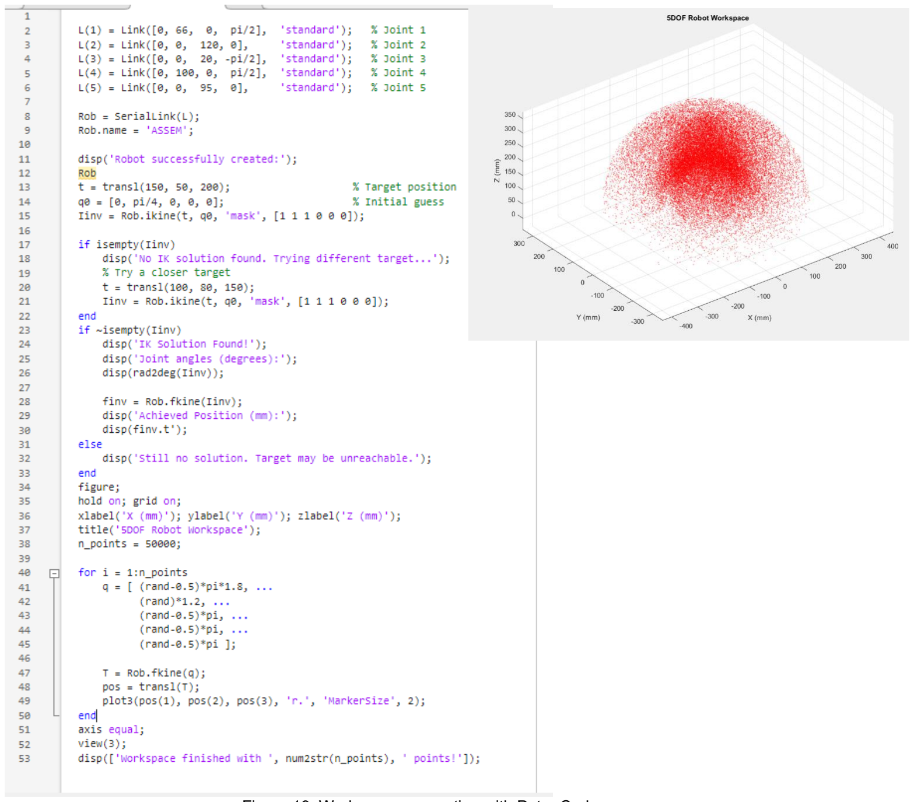
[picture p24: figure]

Figure 19: Workspace generation with Peter Corke

## 4. Electronics and PCB Design

The electrical system of the robot is based on an ESP32 module, an external stepper motor driver, and custom PCBs designed using Altium Designer. The custom electronics were developed to simplify wiring, improve reliability, and organize both the power and control connections inside the system.

The entire system operates from a single 5 V power supply. While the servo motors and ESP32 are powered directly from the 5 V rail, a dedicated boost-converter PCB generates 12 V for the stepper motor driver.

### 1. ESP32 Carrier PCB

This PCB acts as the main controller carrier and signal distribution board for the system. It hosts the ESP32 module and provides organized routing for both power and control signals. The board distributes the 5 V supply to the servo motors, routes PWM control signals from the ESP32, and connects the stepper driver control pins through dedicated headers.

The use of a custom carrier PCB reduces cable clutter, simplifies assembly, improves signal organization, and makes the overall system easier to debug.

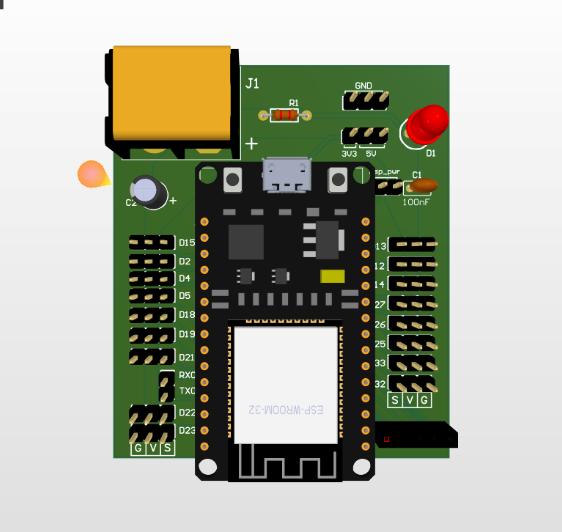
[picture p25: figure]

Figure 20: fabricated PCB photo

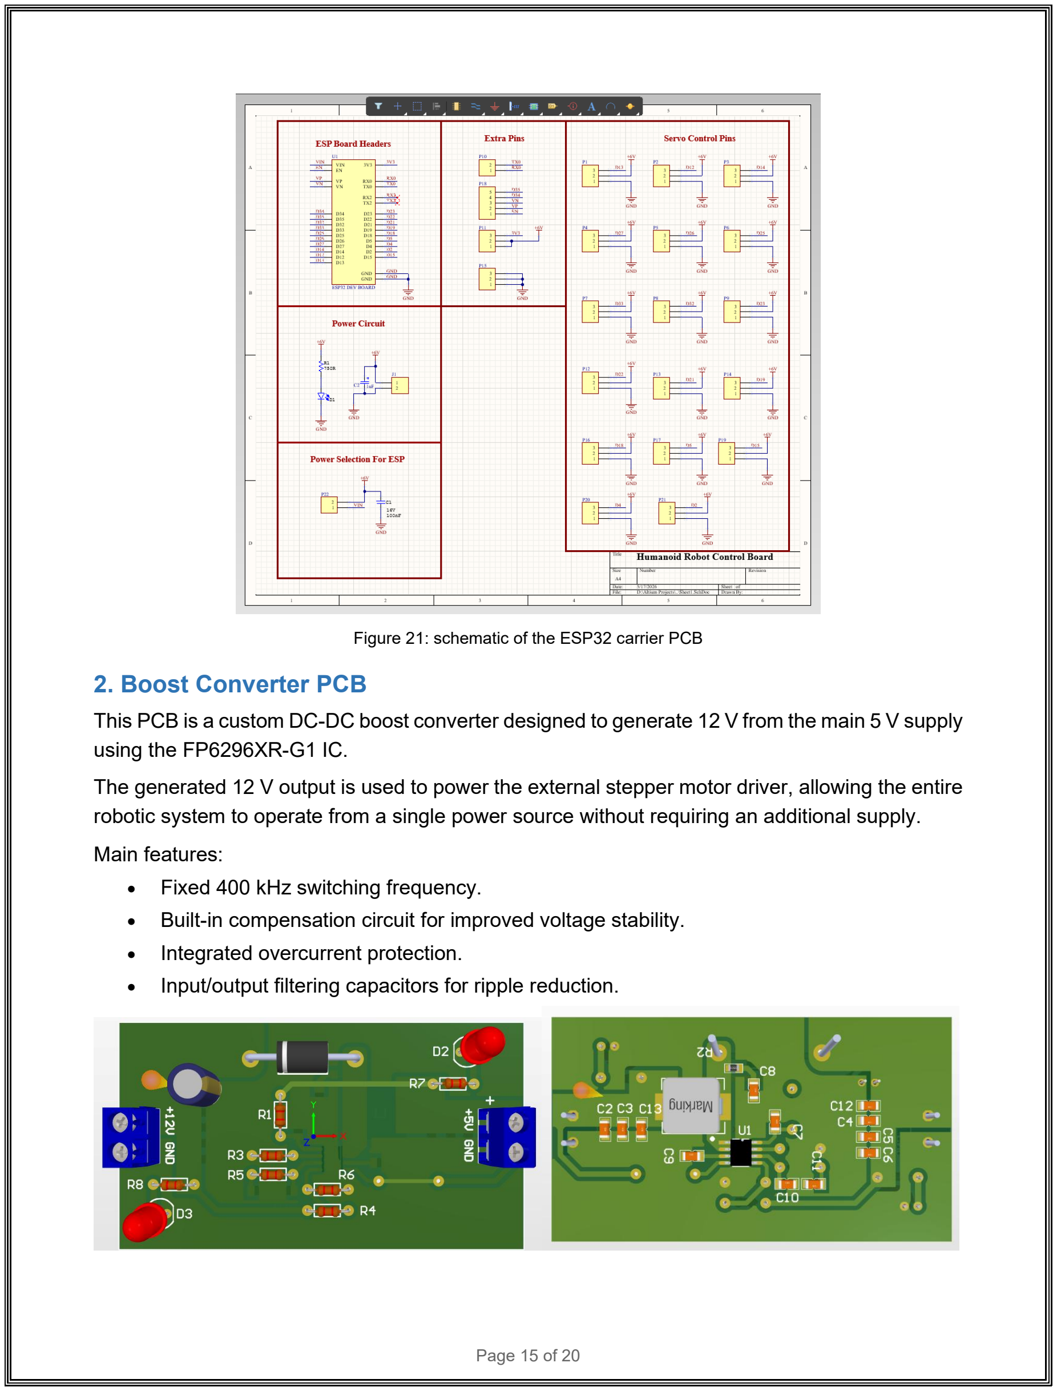
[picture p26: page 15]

Figure 21: schematic of the ESP32 carrier PCB

### 2. Boost Converter PCB

This PCB is a custom DC-DC boost converter designed to generate 12 V from the main 5 V supply using the FP6296XR-G1 IC.

The generated 12 V output is used to power the external stepper motor driver, allowing the entire robotic system to operate from a single power source without requiring an additional supply.

Main features:
- Fixed 400 kHz switching frequency.
- Built-in compensation circuit for improved voltage stability.
- Integrated overcurrent protection.
- Input/output filtering capacitors for ripple reduction.


Figure 22: schematic of the boost converter PCB

## 5. ROS 2 Integration, URDF, Gazebo and MoveIt

### 1. URDF Development and Validation

The robot arm was designed in SolidWorks and exported to URDF format. Before proceeding to motion planning, the URDF must be validated to ensure the conversion preserved all mechanical properties correctly.
Launch command:ros2 launch robot_bringup display.launch.xml
This launch file performs the following:• Loads the URDF into the robot_state_publisher• Starts RViz with a pre-configured view• Allows visual inspection of joint hierarchies, link transformations, and coordinate frames


Figure 23: RViz visualization showing robot URDF

### 2. Motion Planning with MoveIt

Once the URDF is validated, motion planning is performed using MoveIt. The system uses the OMPL (Open Motion Planning Library) planner with KDL (Kinematics and Dynamics Library) for inverse kinematics solving.
The combined launch file brings up the following components:• robot_state_publisher: Publishes the robot's kinematic tree to /tf• ros2_control_node: Manages hardware interfaces and controllers• Controller spawners: Start the joint state broadcaster and arm trajectory controller• move_group: MoveIt's core planning and execution node• RViz: Interactive interface for planning and visualization

### 3. Simulation in Gazebo

Before deploying to real hardware, all planned motions are tested in Gazebo, a physicsbased robot simulator. Gazebo loads the same URDF with additional physics properties and validates that the planned trajectories are executable under realistic conditions.


Figure 24: Gazebo simulation executing a planned trajectory

Benefits of Gazebo simulation:• Safe testing without risk to physical hardware• Visualization of dynamics (gravity, inertia, friction)• Debugging of controller gains and timing• Validation of workspace reachability and collision avoidance

### 4. Gripper Control with PS5 Controller

The robot gripper is controlled using a PS5 controller through ROS2's joy node. This provides intuitive manual control of the end effector while the arm follows planned trajectories.
The joy node publishes button and axis data to the /joy topic, which is then processed by a custom node that translates controller inputs into gripper commands.

Implementation:• joy node interfaces with the PS5 controller via Bluetooth• Custom gripper controller node subscribes to /joy topic• Button presses are mapped to gripper open/close commands• Commands are sent to the ESP32 via the serial bridge

### 5. Hardware Deployment via ESP32

After validating motions in simulation, the same trajectories are sent to the physical robot arm. A custom ROS2 node subscribes to the /joint_states topic and forwards joint angles to an ESP32 microcontroller via serial communication.

Serial Communication Node
A dedicated ROS2 node acts as a bridge between the high-level ROS2 system and the low-level hardware:
Functionality:• Subscribes to /joint_states topic• Extracts joint position data• Formats commands for ESP32 (comma-separated angles)• Transmits via UART at 115200 baud• Receives acknowledgment/feedback from ESP32

ESP32 Responsibilities
The ESP32 microcontroller handles the low-level actuation:• Receives joint angle commands via UART• Converts angles to servo PWM signals• Drives servo motors with appropriate timing• Implements safety limits to prevent mechanical damage• Optionally sends position feedback to ROS2

Communication Protocol
- Baud rate: 115200• Data format: Comma-separated angles• Example: "45.2,90.0,-30.5,120.0\n"

## 6. Results and Achievements

✓ Complete URDF model extracted from SolidWorks✓ Motion planning with collision avoidance in MoveIt✓ Gazebo simulation matching physical robot kinematics✓ Realtime joint state publishing and visualization✓ PS5 controller integration for gripper control✓ Serial communication bridge to ESP32 hardware✓ Unified launch files for integrated workflows

## 6. Conclusion

This project successfully demonstrated a complete robotics software stack, from CAD modeling to hardware deployment. By integrating MoveIt for planning, Gazebo for simulation, and custom nodes for hardware interfacing, we created a robust system that bridges the gap between virtual and physical robotics.
The workflow validates the importance of simulation in robotics development—enabling safe, rapid iteration before deploying to expensive hardware. The ROS2 ecosystem provided the modular architecture necessary to compartmentalize functionality while maintaining seamless integration between different subsystems.

The addition of PS5 controller integration for gripper control demonstrated how modern gaming peripherals can be effectively used as intuitive human-robot interfaces. The serial communication bridge to ESP32 showcased how ROS2 can be extended to work with low-cost embedded systems, making advanced robotics capabilities accessible without expensive hardware.

## 7. Appendix: Running the Project

### 1 Launch Simulation + MoveIt

cd ~/robot_arm && source install/setup.bash && ros2 launch arm_description moevit_gazebo.launch.py

### 2 Launch URDF Visualization

ros2 launch arm_description display.launch.xml

### 3 Start Serial Communication Node

ros2 run arm_control control_serial

### 4 Start Joy Node for PS5 Controller

ros2 run joy joy_node

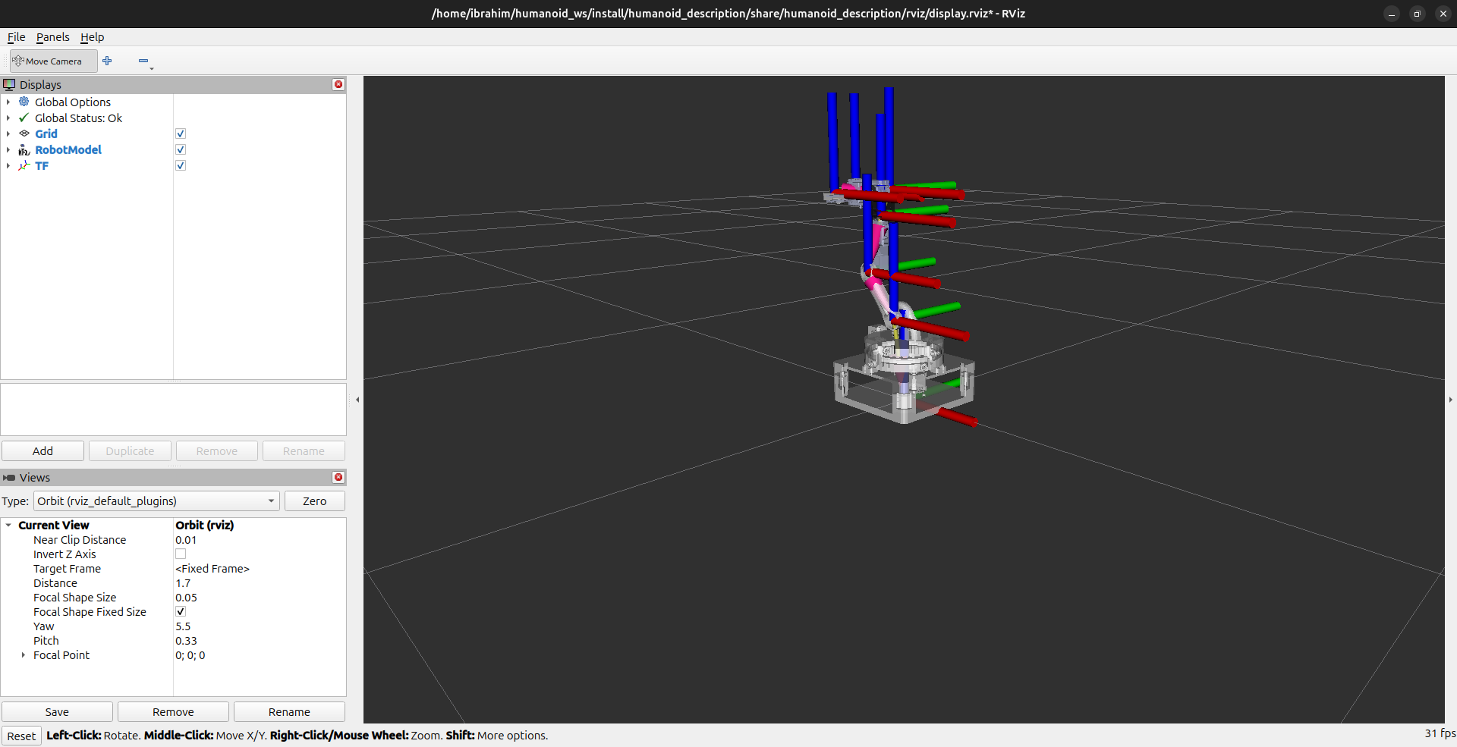
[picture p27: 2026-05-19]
media/screenshots/tfs.png

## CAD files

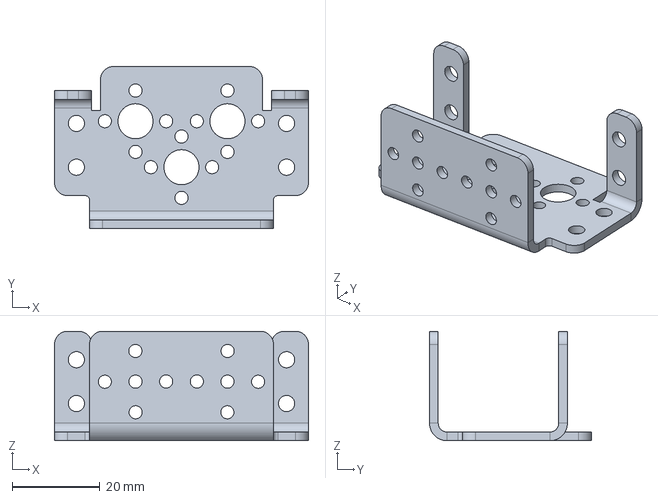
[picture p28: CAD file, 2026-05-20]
CAD/Solidoworks/Servo Bracket - universal v10.step
58.0 x 37.0 x 25.0 mm

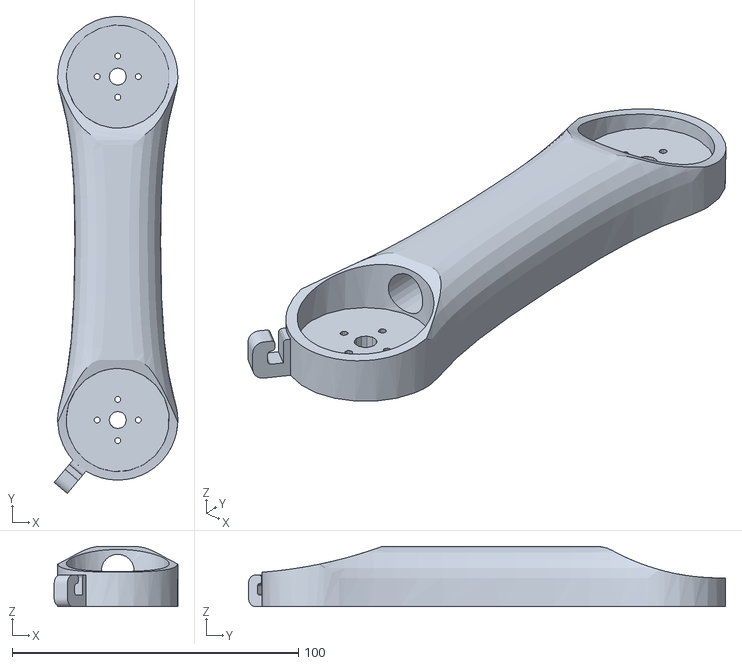
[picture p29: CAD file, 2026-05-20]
CAD/STL/Arm 01.STL
43.2 x 166.7 x 21.0

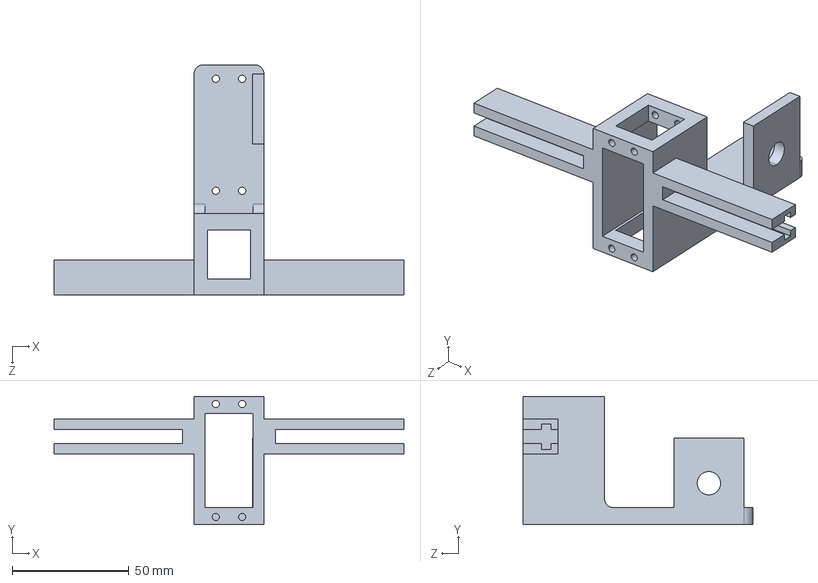
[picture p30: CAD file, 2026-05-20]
matlab/Servo holder_Default_sldprt.STEP
150.0 x 55.0 x 98.8 mm

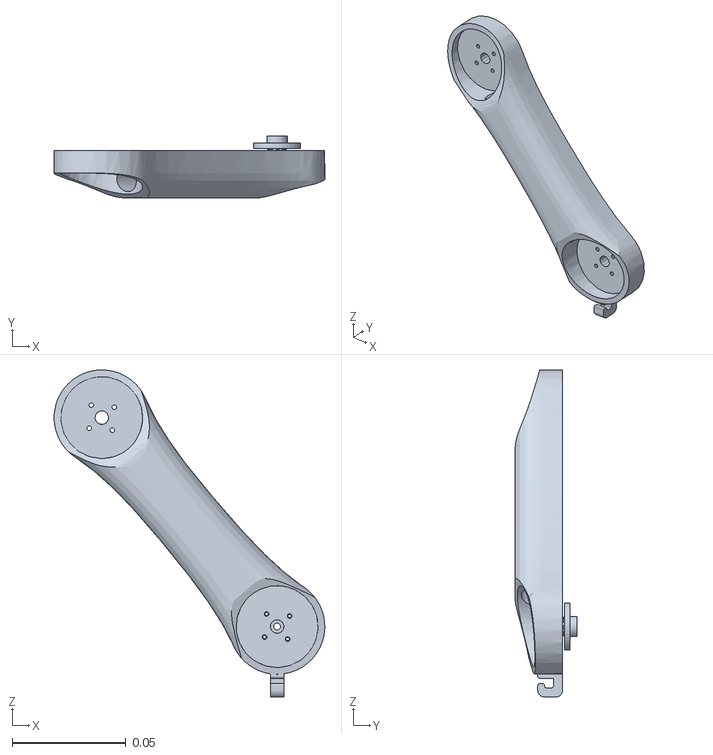
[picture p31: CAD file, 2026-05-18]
robot_arm/src/arm_description/meshes/link_1.STL
0.119 x 0.0273 x 0.144

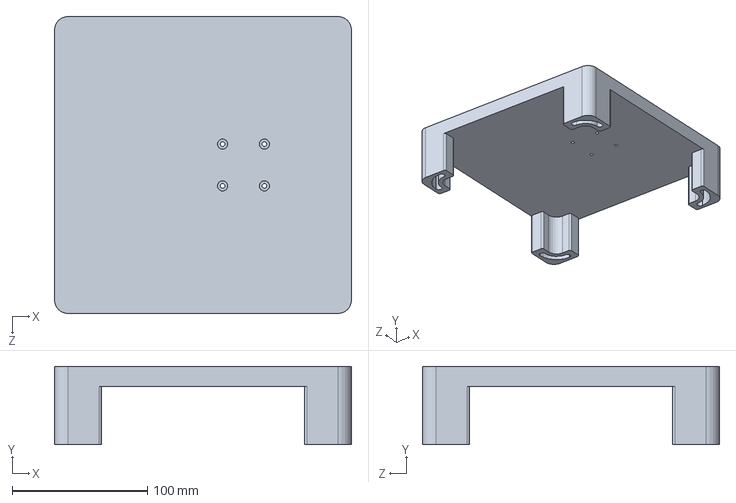
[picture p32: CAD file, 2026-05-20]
CAD/Solidoworks/lower base.SLDPRT
220.0 x 58.0 x 220.0 mm

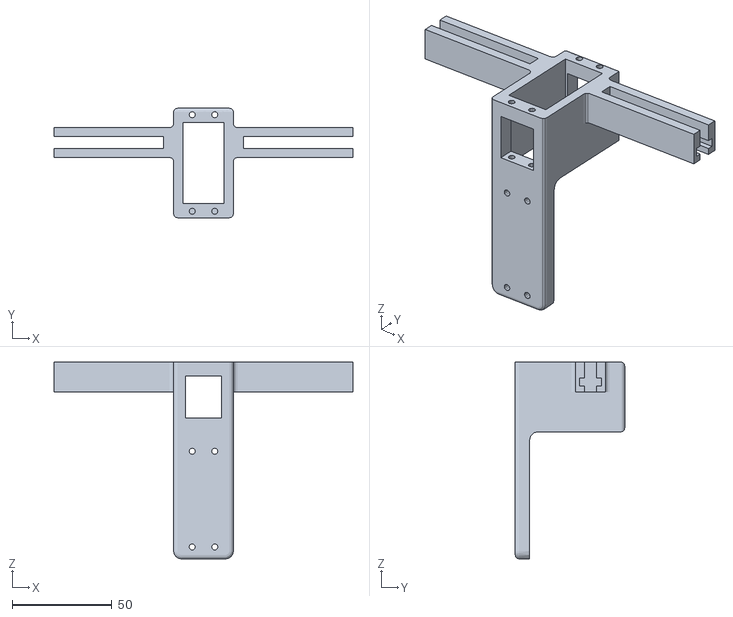
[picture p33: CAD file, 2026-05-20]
CAD/STL/Servo holder.STL
150.0 x 55.0 x 98.8

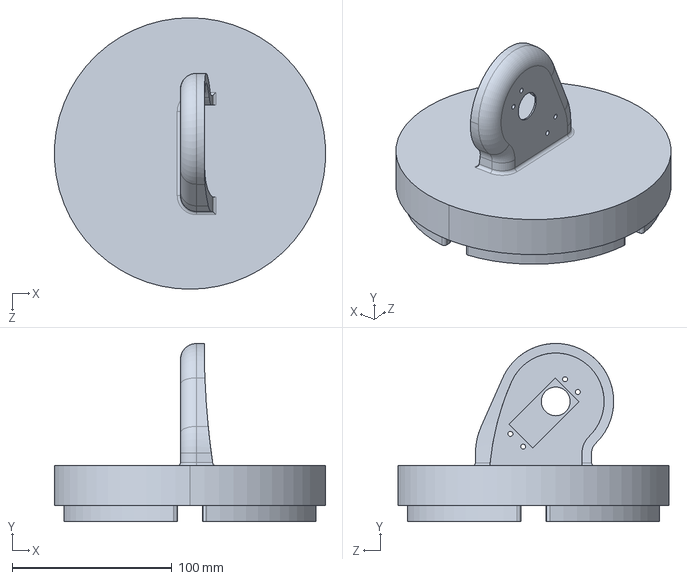
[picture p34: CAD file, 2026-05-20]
matlab/cap_Default_sldprt.STEP
169.8 x 111.6 x 170.0 mm

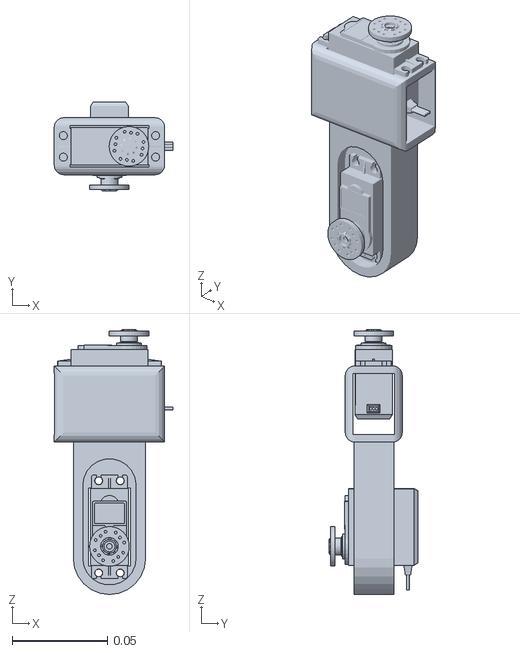
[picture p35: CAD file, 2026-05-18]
robot_arm/src/arm_description/meshes/link_2.STL
0.0622 x 0.0469 x 0.139

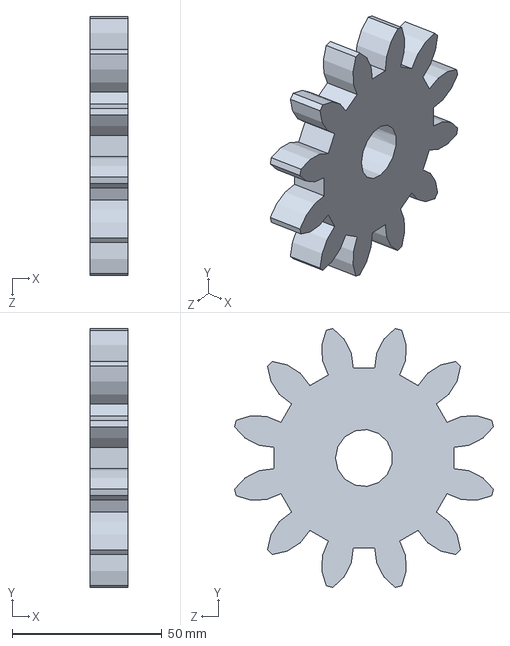
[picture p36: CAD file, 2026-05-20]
CAD/Solidoworks/spur gear_am.sldprt
12.7 x 86.4 x 86.4 mm

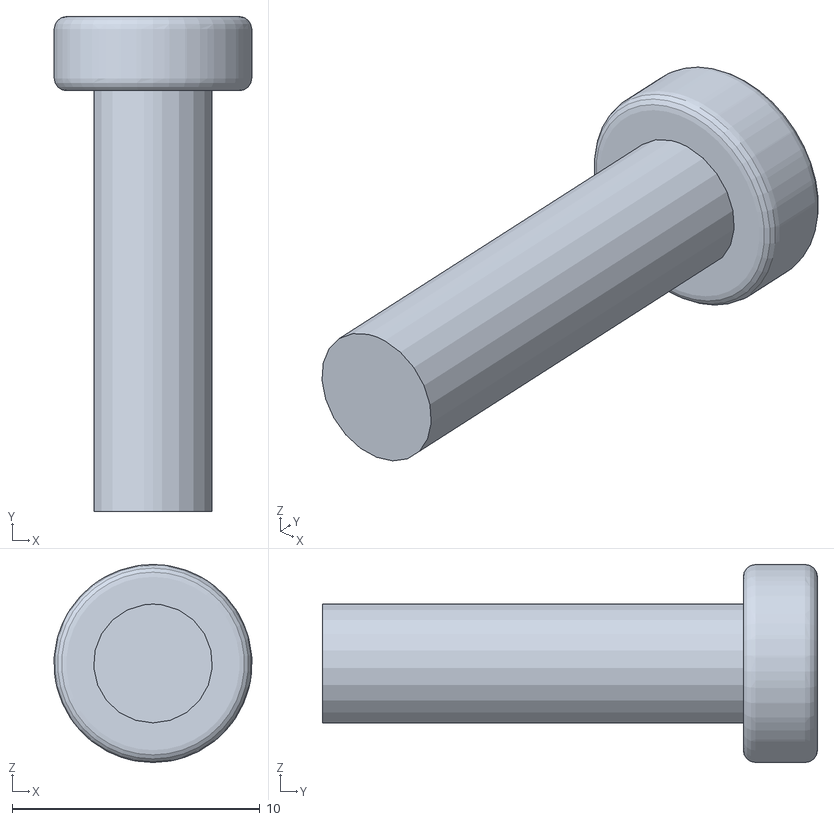
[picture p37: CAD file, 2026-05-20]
CAD/STL/pin(x10).STL
7.99 x 20.0 x 8.00

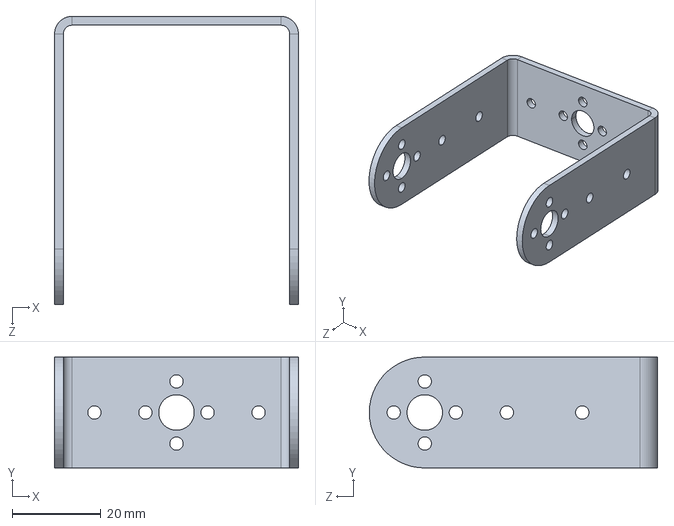
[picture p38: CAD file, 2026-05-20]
matlab/Servo Bracket - long U.step_Default_sldprt.STEP
55.0 x 25.0 x 65.0 mm

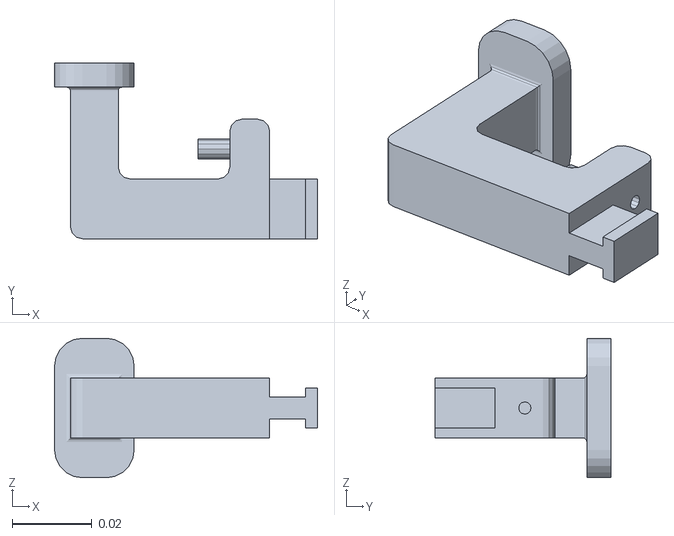
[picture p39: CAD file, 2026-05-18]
robot_arm/src/arm_description/meshes/left_clamp_link.STL
0.066 x 0.0441 x 0.035

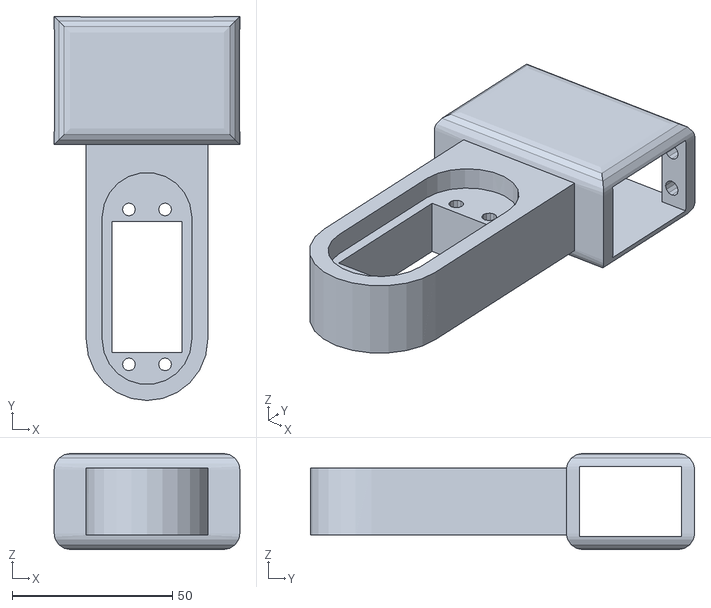
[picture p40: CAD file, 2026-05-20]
CAD/STL/link2_us.STL
58.0 x 120.0 x 30.0

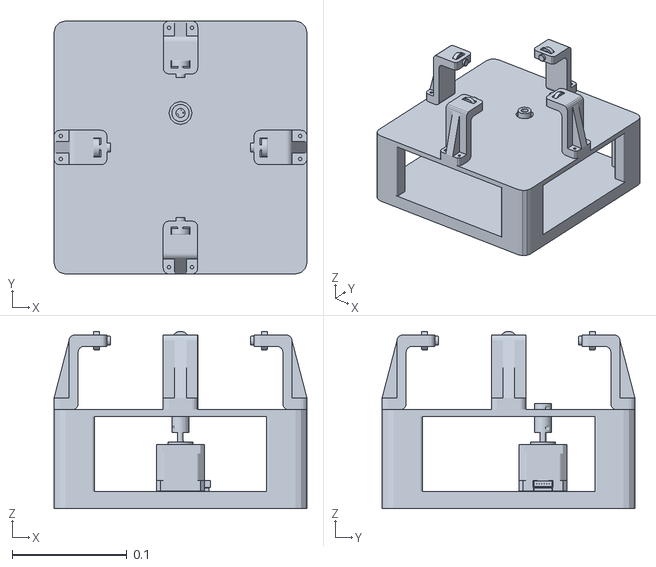
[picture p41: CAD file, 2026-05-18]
robot_arm/src/arm_description/meshes/base_link.STL
0.22 x 0.22 x 0.154

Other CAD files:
CAD/Solidoworks/Full_aseembly.SLDASM
CAD/Solidoworks/Servo holder.SLDPRT
matlab/Arm 01_Default_sldprt.STEP
CAD/Solidoworks/Gear_guide.SLDPRT
CAD/STL/Gear_guide(x4).STL
CAD/STL/Gripper Arm(x2).STL
CAD/STL/Internal_gear.STL
CAD/STL/Servo_Arm_link(x2).STL
CAD/STL/cap.STL
CAD/STL/lower base.STL
CAD/STL/spur gear_with_shaft.STL
CAD/STL/upper base.STL
CAD/Solidoworks/Arm 01.SLDPRT
CAD/Solidoworks/Gripper Armx2.SLDPRT
CAD/Solidoworks/Internal_gear.SLDPRT
CAD/Solidoworks/Nima 17 40x42x5mm.SLDPRT
CAD/Solidoworks/Servo Bracket - long U v3.step
CAD/Solidoworks/Servo_Arm_link.SLDPRT
CAD/Solidoworks/cap.SLDPRT
CAD/Solidoworks/coupler.SLDPRT
CAD/Solidoworks/instrument ball bearing_68_am.sldprt
CAD/Solidoworks/link2_us (1).SLDPRT
CAD/Solidoworks/mg996_arm_2pad.step
CAD/Solidoworks/mg996_arm_round.step
CAD/Solidoworks/pin.SLDPRT
CAD/Solidoworks/servo_without_face.SLDPRT
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

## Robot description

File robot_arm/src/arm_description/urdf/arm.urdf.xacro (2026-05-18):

<?xml version="1.0" encoding="utf-8"?>
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
<robot xmlns:xacro="https://www.ros.arg/wiki.xacro" name="robot_arm">
  <link name="base_footprint" />
  <link name="base_link">
    <inertial>
      <origin xyz="5.00753655452435E-06 0.00106730808800359 0.0399725317757015" rpy="0 0 0" />
      <mass value="1.96669728638092" />
      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
    </inertial>
    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
  </link>
  <joint name="base_joint" type="fixed">
    <parent link="base_footprint" />
    <child link="base_link" />
    <origin rpy="0 0 0" xyz="0 0 0" />
  </joint>
  <link name="gears_link">
    <inertial>
      <origin xyz="-0.000646482723518194 0.000582676567977392 0.120933732816505" rpy="0 0 0" />
      <mass value="1.30703305083613" />
      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
    </inertial>
    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
  </link>
  <joint name="stepper_joint" type="continuous">
    <origin xyz="0 0 0" rpy="0 0 0" />
    <parent link="base_link" />
    <child link="gears_link" />
    <axis xyz="0 0 1" />
  </joint>
  <link name="link_1">
    <inertial>
      <origin xyz="-0.0374079774245866 -0.00165911196637181 0.0443811892357548" rpy="0 0 0" />
      <mass value="0.0925850477466471" />
      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
    </inertial>
    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
  </link>
  <joint name="joint_1" type="revolute">
    <origin xyz="-0.0139089123190268 -0.0164898687365239 0.177428154723944" rpy="0 0 0" />
    <parent link="gears_link" />
    <child link="link_1" />
    <axis xyz="0 1 0" />
    <limit lower="-1.57" upper="1.57" effort="0" velocity="0" />
  </joint>
  <link name="link_2">
    <inertial>
      <origin xyz="0.000120042512608443 0.0305979287540822 0.0437360389039791" rpy="0 0 0" />
      <mass value="0.148049393384596" />
      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
    </inertial>
    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
  </link>
  <joint name="joint_2" type="revolute">
    <origin xyz="-0.0771345131623846 0 0.0919253331742771" rpy="0 0 0" />
    <parent link="link_1" />
    <child link="link_2" />
    <axis xyz="0 -1 0" />
    <limit lower="-1.57" upper="1.57" effort="0" velocity="0" />
  </joint>
  <link name="bracket_1">
    <inertial>
      <origin xyz="-8.88178419700125E-16 -1.11022302462516E-16 0.020100181267799" rpy="0 0 0" />
      <mass value="0.00809692470259986" />
      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
    </inertial>
    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
  </link>
  <joint name="bracket_1_joint" type="revolute">
    <origin xyz="0.0102500000000005 0.0295299999999998 0.115849999999999" rpy="0 0 0" />
    <parent link="link_2" />
    <child link="bracket_1" />
    <axis xyz="0 0 -1" />
    <limit lower="-1.57" upper="1.57" effort="0" velocity="0" />
  </joint>
  <link name="end_effector_link">
    <inertial>
      <origin xyz="-0.0444277269513493 -0.0296709800292212 -0.00252321817991552" rpy="0 0 0" />
      <mass value="0.140812329806381" />
      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
    </inertial>
    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
  </link>
  <joint name="end_effector_joint" type="revolute">
    <origin xyz="0 0.0239999999999756 0.0504999999999962" rpy="0 0 0" />
    <parent link="bracket_1" />
    <child link="end_effector_link" />
    <axis xyz="0 -1 0" />
    <limit lower="-1.57" upper="1.57" effort="0" velocity="0" />
  </joint>
  <link name="left_clamp_link">
    <inertial>
      <origin xyz="-0.0013935388930264 0.00464113678666978 -0.00749999927742095" rpy="0 0 0" />
      <mass value="0.0323665959300894" />
      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
    </inertial>
    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
  </link>
  <joint name="lefft_clamp_joint" type="prismatic">
    <origin xyz="-0.105566455801366 -0.0610142944129759 -0.00859999999999328" rpy="0 0 0" />
    <parent link="end_effector_link" />
    <child link="left_clamp_link" />
    <axis xyz="0 -1 0" />
    <limit lower="0" upper="0.05" effort="0" velocity="0" />
  </joint>
  <link name="right_clamp">
    <inertial>
      <origin xyz="-0.00139353889303906 -0.00464113678631295 -0.0075000007226167" rpy="0 0 0" />
      <mass value="0.0323665959300896" />
      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
    </inertial>
    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
  </link>
  <joint name="right_clamp_joint" type="prismatic">
    <origin xyz="-0.105566455801366 -0.000148461531559452 -0.00859999999999284" rpy="0 0 0" />
    <parent link="end_effector_link" />
    <child link="right_clamp" />
    <axis xyz="0 -1 0" />
    <limit lower="-0.05" upper="0.0" effort="0" velocity="0" />
  </joint>
</robot>

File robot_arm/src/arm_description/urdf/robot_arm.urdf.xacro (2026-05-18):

<?xml version="1.0" encoding="utf-8"?>
<robot xmlns:xacro="http://www.ros.org/wiki/xacro" name="robot_arm">

  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
  <xacro:property name="joint_lower" value="-1.57" />
  <xacro:property name="joint_upper" value="1.57" />
  <xacro:property name="joint_effort" value="10.0" />
  <xacro:property name="joint_vel" value="1.0" />

  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
  <xacro:property name="gripper_effort" value="5.0" />
  <xacro:property name="gripper_vel" value="0.1" />

  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
  <xacro:property name="damping" value="0.1" />

  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
  <xacro:property name="mesh_pkg" value="arm_description" />

  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
  <xacro:macro name="revolute_ros2_control" params="joint_name j_min:=-1.57 j_max:=1.57">
    <joint name="${joint_name}">
      <command_interface name="position">
        <param name="min">${j_min}</param>
        <param name="max">${j_max}</param>
      </command_interface>
      <state_interface name="position"/>
      <state_interface name="velocity"/>
    </joint>
  </xacro:macro>

  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
  <xacro:macro name="passive_ros2_control" params="joint_name">
    <joint name="${joint_name}">
      <state_interface name="position"/>
      <state_interface name="velocity"/>
    </joint>
  </xacro:macro>

  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

  <link name="base_footprint" />

  <link name="base_link">
    <inertial>
      <origin xyz="5.00753655452435E-06 0.00106730808800359 0.0399725317757015" rpy="0 0 0" />
      <mass value="1.96669728638092" />
      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
    </inertial>
    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
  </link>

  <link name="gears_link">
    <inertial>
      <origin xyz="-0.000646482723518194 0.000582676567977392 0.120933732816505" rpy="0 0 0" />
      <mass value="1.30703305083613" />
      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
    </inertial>
    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
  </link>

  <link name="link_1">
    <inertial>
      <origin xyz="-0.0374079774245866 -0.00165911196637181 0.0443811892357548" rpy="0 0 0" />
      <mass value="0.0925850477466471" />
      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
    </inertial>
    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
  </link>

  <link name="link_2">
    <inertial>
      <origin xyz="0.000120042512608443 0.0305979287540822 0.0437360389039791" rpy="0 0 0" />
      <mass value="0.148049393384596" />
      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
    </inertial>
    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
  </link>

  <link name="bracket_1">
    <inertial>
      <origin xyz="-8.88178419700125E-16 -1.11022302462516E-16 0.020100181267799" rpy="0 0 0" />
      <mass value="0.00809692470259986" />
      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
    </inertial>
    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
  </link>

  <link name="end_effector_link">
    <inertial>
      <origin xyz="-0.0444277269513493 -0.0296709800292212 -0.00252321817991552" rpy="0 0 0" />
      <mass value="0.140812329806381" />
      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
    </inertial>
    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
  </link>

  <link name="left_clamp_link">
    <inertial>
      <origin xyz="-0.0013935388930264 0.00464113678666978 -0.00749999927742095" rpy="0 0 0" />
      <mass value="0.0323665959300894" />
      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
    </inertial>
    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
  </link>

  <link name="right_clamp">
    <inertial>
      <origin xyz="-0.00139353889303906 -0.00464113678631295 -0.0075000007226167" rpy="0 0 0" />
      <mass value="0.0323665959300896" />
      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
    </inertial>
    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
  </link>

  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

  <joint name="base_joint" type="fixed">
    <parent link="base_footprint" />
    <child link="base_link" />
    <origin rpy="0 0 0" xyz="0 0 0" />
  </joint>

  <joint name="stepper_joint" type="continuous">
    <origin xyz="0 0 0" rpy="0 0 0" />
    <parent link="base_link" />
    <child link="gears_link" />
    <axis xyz="0 0 1" />
    <limit effort="${joint_effort}" velocity="${joint_vel}" />
  </joint>

  <joint name="joint_1" type="revolute">
    <origin xyz="-0.0139089123190268 -0.0164898687365239 0.177428154723944" rpy="0 0 0" />
    <parent link="gears_link" />
    <child link="link_1" />
    <axis xyz="0 1 0" />
    <limit lower="${joint_lower}" upper="${joint_upper}" effort="${joint_effort}" velocity="${joint_vel}" />
  </joint>

  <joint name="joint_2" type="revolute">
    <origin xyz="-0.0771345131623846 0 0.0919253331742771" rpy="0 0 0" />
    <parent link="link_1" />
    <child link="link_2" />
    <axis xyz="0 -1 0" />
    <limit lower="${joint_lower}" upper="${joint_upper}" effort="${joint_effort}" velocity="${joint_vel}" />
  </joint>

  <joint name="bracket_1_joint" type="revolute">
    <origin xyz="0.0102500000000005 0.0295299999999998 0.115849999999999" rpy="0 0 0" />
    <parent link="link_2" />
    <child link="bracket_1" />
    <axis xyz="0 0 -1" />
    <limit lower="${joint_lower}" upper="${joint_upper}" effort="${joint_effort}" velocity="${joint_vel}" />
  </joint>

  <joint name="end_effector_joint" type="revolute">
    <origin xyz="0 0.0239999999999756 0.0504999999999962" rpy="0 0 0" />
    <parent link="bracket_1" />
    <child link="end_effector_link" />
    <axis xyz="0 -1 0" />
    <limit lower="${joint_lower}" upper="${joint_upper}" effort="${joint_effort}" velocity="${joint_vel}" />
  </joint>

  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
  <joint name="lefft_clamp_joint" type="prismatic">
    <origin xyz="-0.105566455801366 -0.0610142944129759 -0.00859999999999328" rpy="0 0 0" />
    <parent link="end_effector_link" />
    <child link="left_clamp_link" />
    <axis xyz="0 -1 0" />
    <limit lower="0" upper="0.05" effort="${gripper_effort}" velocity="${gripper_vel}" />
  </joint>

  <joint name="right_clamp_joint" type="prismatic">
    <origin xyz="-0.105566455801366 -0.000148461531559452 -0.00859999999999284" rpy="0 0 0" />
    <parent link="end_effector_link" />
    <child link="right_clamp" />
    <axis xyz="0 -1 0" />
    <limit lower="-0.05" upper="0.0" effort="${gripper_effort}" velocity="${gripper_vel}" />
  </joint>

  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

  <ros2_control name="GazeboSystem" type="system">
    <hardware>
      <plugin>gz_ros2_control/GazeboSimSystem</plugin>
    </hardware>

    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
    <joint name="stepper_joint">
      <command_interface name="position"/>
      <state_interface name="position"/>
      <state_interface name="velocity"/>
    </joint>

    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
    <xacro:revolute_ros2_control joint_name="joint_1" j_min="-1.57" j_max="1.57" />
    <xacro:revolute_ros2_control joint_name="joint_2" j_min="-1.57" j_max="1.57" />
    <xacro:revolute_ros2_control joint_name="bracket_1_joint" j_min="-1.57" j_max="1.57" />
    <xacro:revolute_ros2_control joint_name="end_effector_joint" j_min="-1.57" j_max="1.57" />

    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
    <xacro:passive_ros2_control joint_name="lefft_clamp_joint" />
    <xacro:passive_ros2_control joint_name="right_clamp_joint" />

  </ros2_control>

  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

</robot>

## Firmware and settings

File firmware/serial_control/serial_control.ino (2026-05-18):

#include <ESP32Servo.h>

// =====================================================
// SERVOS
// =====================================================

Servo joint1Servo;
Servo joint2Servo;

Servo bracketServo;
Servo endEffectorServo;

Servo gripperServo;

// =====================================================
// PINS
// =====================================================

#define JOINT1_PIN          13
#define JOINT2_PIN          12

#define BRACKET_PIN         14
#define END_EFFECTOR_PIN    27

#define GRIPPER_PIN         26

// =====================================================
// STEPPER PINS
// =====================================================

#define STEP_PIN    18
#define DIR_PIN     19

// =====================================================
// CURRENT POSITIONS
// =====================================================

int currentStepperAngle = 0;

// =====================================================
// SETUP
// =====================================================

void setup()
{
    Serial.begin(115200);

    // ================= SERVO ATTACH =================

    joint1Servo.attach(JOINT1_PIN);
    joint2Servo.attach(JOINT2_PIN);

    bracketServo.attach(BRACKET_PIN);
    endEffectorServo.attach(END_EFFECTOR_PIN);

    gripperServo.attach(GRIPPER_PIN);

    // ================= STEPPER =================

    pinMode(STEP_PIN, OUTPUT);
    pinMode(DIR_PIN, OUTPUT);

    // ================= INITIAL POSITIONS =================

    joint1Servo.write(90);
    joint2Servo.write(90);

    bracketServo.write(90);
    endEffectorServo.write(90);

    gripperServo.write(90);

    Serial.println("ESP32 Ready");
}

// =====================================================
// LOOP
// =====================================================

void loop()
{
    if (Serial.available())
    {
        String received = Serial.readStringUntil('\n');

        received.trim();

        if (received.length() > 0)
        {
            processData(received);
        }
    }
}

// =====================================================
// PROCESS SERIAL DATA
// =====================================================

void processData(String data)
{
    // Expected format:
    //
    // stepper,joint1,joint2,bracket,end_effector,gripper
    //
    // Example:
    // 0,90,90,90,90,45

    int values[6];

    int index = 0;

    char charArray[100];

    data.toCharArray(charArray, 100);

    char *token = strtok(charArray, ",");

    while (token != NULL && index < 6)
    {
        values[index] = atoi(token);

        token = strtok(NULL, ",");

        index++;
    }

    // Must receive exactly 6 values
    if (index != 6)
    {
        Serial.println("Invalid packet");
        return;
    }

    // =====================================================
    // EXTRACT VALUES
    // =====================================================

    int stepperAngle     = values[0];

    int joint1Angle      = values[1];
    int joint2Angle      = values[2];

    int bracketAngle     = values[3];
    int endEffectorAngle = values[4];

    int gripperAngle     = values[5];

    // =====================================================
    // CLAMP SAFETY
    // =====================================================

    joint1Angle = constrain(joint1Angle, 0, 180);
    joint2Angle = constrain(joint2Angle, 0, 180);

    bracketAngle = constrain(bracketAngle, 0, 180);
    endEffectorAngle = constrain(endEffectorAngle, 0, 180);

    gripperAngle = constrain(gripperAngle, 0, 180);

    // =====================================================
    // WRITE SERVOS
    // =====================================================

    joint1Servo.write(joint1Angle);
    joint2Servo.write(joint2Angle);

    bracketServo.write(bracketAngle);
    endEffectorServo.write(endEffectorAngle);

    gripperServo.write(gripperAngle);

    // =====================================================
    // MOVE STEPPER
    // =====================================================

    moveStepperTo(stepperAngle);

    // =====================================================
    // DEBUG PRINT
    // =====================================================

    Serial.print("Stepper: ");
    Serial.print(stepperAngle);

    Serial.print(" | J1: ");
    Serial.print(joint1Angle);

    Serial.print(" | J2: ");
    Serial.print(joint2Angle);

    Serial.print(" | Bracket: ");
    Serial.print(bracketAngle);

    Serial.print(" | EE: ");
    Serial.print(endEffectorAngle);

    Serial.print(" | Gripper: ");
    Serial.println(gripperAngle);
}

// =====================================================
// SIMPLE STEPPER CONTROL
// =====================================================

void moveStepperTo(int targetAngle)
{
    int difference = targetAngle - currentStepperAngle;

    if (difference == 0)
        return;

    // Direction
    if (difference > 0)
    {
        digitalWrite(DIR_PIN, HIGH);
    }
    else
    {
        digitalWrite(DIR_PIN, LOW);

        difference = -difference;
    }

    // =====================================================
    // CONVERT ANGLE TO STEPS
    // =====================================================

    // Example:
    // 200 step motor
    // 1.8 deg/step

    int steps = difference / 1.8;

    // =====================================================
    // PULSE STEPPER
    // =====================================================

    for (int i = 0; i < steps; i++)
    {
        digitalWrite(STEP_PIN, HIGH);
        delayMicroseconds(5000);

        digitalWrite(STEP_PIN, LOW);
        delayMicroseconds(5000);
    }

    currentStepperAngle = targetAngle;
}

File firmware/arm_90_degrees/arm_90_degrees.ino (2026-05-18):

#include <ESP32Servo.h>

#define servo1_pin 13
#define servo2_pin 12
#define servo3_pin 14
#define servo4_pin 27
#define servo5_pin 26

Servo servo1;
  Servo servo2;
  Servo servo3;
  Servo servo4;
  Servo servo5;
void setup() {
  

  servo1.attach(servo1_pin);
  servo2.attach(servo2_pin);
  servo3.attach(servo3_pin);  
  servo4.attach(servo4_pin);
  servo5.attach(servo5_pin);
  delay(1000);
  // put your setup code here, to run once:

}

void loop() {
  servo1.write(0); //130 by2fel 0 byfta7 lel a5er
  servo2.write(0); //180 bynzel le ta7t 
  servo3.write(40); //angle a2al mn 90 bylegf ymeen  
  servo4.write(140); //angle so8ayar le odam angle kbeer le wara
  servo5.write(40); //angle so8ayar le wara 

  for (int i=20;i<=160 ;i++)
    {
      servo4.write(i);
      delay(50);
    }
    servo1.write(130);
  delay(500);
   for (int i=160;i>=20 ;i--)
    {
      servo4.write(i);
      delay(50);
    }
  servo1.write(0);
}

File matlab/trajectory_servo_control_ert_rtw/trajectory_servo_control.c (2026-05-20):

/*
 * File: trajectory_servo_control.c
 *
 * Code generated for Simulink model 'trajectory_servo_control'.
 *
 * Model version                  : 1.4
 * Simulink Coder version         : 24.1 (R2024a) 19-Nov-2023
 * C/C++ source code generated on : Mon May 18 10:21:15 2026
 *
 * Target selection: ert.tlc
 * Embedded hardware selection: ARM Compatible->ARM Cortex
 * Code generation objectives: Unspecified
 * Validation result: Not run
 */

#include "trajectory_servo_control.h"
#include "trajectory_servo_control_private.h"
#include <math.h>
#include "rtwtypes.h"

/* Block states (default storage) */
DW_trajectory_servo_control_T trajectory_servo_control_DW;

/* Real-time model */
static RT_MODEL_trajectory_servo_con_T trajectory_servo_control_M_;
RT_MODEL_trajectory_servo_con_T *const trajectory_servo_control_M =
  &trajectory_servo_control_M_;
static void rate_monotonic_scheduler(void);
real_T look1_binlcpw(real_T u0, const real_T bp0[], const real_T table[],
                     uint32_T maxIndex)
{
  real_T frac;
  real_T yL_0d0;
  uint32_T bpIdx;
  uint32_T iLeft;
  uint32_T iRght;

  /* Column-major Lookup 1-D
     Search method: 'binary'
     Use previous index: 'off'
     Interpolation method: 'Linear point-slope'
     Extrapolation method: 'Clip'
     Use last breakpoint for index at or above upper limit: 'off'
     Remove protection against out-of-range input in generated code: 'off'
   */
  /* Prelookup - Index and Fraction
     Index Search method: 'binary'
     Extrapolation method: 'Clip'
     Use previous index: 'off'
     Use last breakpoint for index at or above upper limit: 'off'
     Remove protection against out-of-range input in generated code: 'off'
   */
  if (u0 <= bp0[0U]) {
    iLeft = 0U;
    frac = 0.0;
  } else if (u0 < bp0[maxIndex]) {
    /* Binary Search */
    bpIdx = maxIndex >> 1U;
    iLeft = 0U;
    iRght = maxIndex;
    while (iRght - iLeft > 1U) {
      if (u0 < bp0[bpIdx]) {
        iRght = bpIdx;
      } else {
        iLeft = bpIdx;
      }

      bpIdx = (iRght + iLeft) >> 1U;
    }

    frac = (u0 - bp0[iLeft]) / (bp0[iLeft + 1U] - bp0[iLeft]);
  } else {
    iLeft = maxIndex - 1U;
    frac = 1.0;
  }

  /* Column-major Interpolation 1-D
     Interpolation method: 'Linear point-slope'
     Use last breakpoint for index at or above upper limit: 'off'
     Overflow mode: 'portable wrapping'
   */
  yL_0d0 = table[iLeft];
  return (table[iLeft + 1U] - yL_0d0) * frac + yL_0d0;
}

/*
 * Set which subrates need to run this base step (base rate always runs).
 * This function must be called prior to calling the model step function
 * in order to remember which rates need to run this base step.  The
 * buffering of events allows for overlapping preemption.
 */
void trajectory_servo_control_SetEventsForThisBaseStep(boolean_T *eventFlags)
{
  /* Task runs when its counter is zero, computed via rtmStepTask macro */
  eventFlags[1] = ((boolean_T)rtmStepTask(trajectory_servo_control_M, 1));
}

/*
 *         This function updates active task flag for each subrate
 *         and rate transition flags for tasks that exchange data.
 *         The function assumes rate-monotonic multitasking scheduler.
 *         The function must be called at model base rate so that
 *         the generated code self-manages all its subrates and rate
 *         transition flags.
 */
static void rate_monotonic_scheduler(void)
{
  /* Compute which subrates run during the next base time step.  Subrates
   * are an integer multiple of the base rate counter.  Therefore, the subtask
   * counter is reset when it reaches its limit (zero means run).
   */
  (trajectory_servo_control_M->Timing.TaskCounters.TID[1])++;
  if ((trajectory_servo_control_M->Timing.TaskCounters.TID[1]) > 1) {/* Sample time: [0.01s, 0.0s] */
    trajectory_servo_control_M->Timing.TaskCounters.TID[1] = 0;
  }
}

real_T rt_roundd_snf(real_T u)
{
  real_T y;
  if (fabs(u) < 4.503599627370496E+15) {
    if (u >= 0.5) {
      y = floor(u + 0.5);
    } else if (u > -0.5) {
      y = u * 0.0;
    } else {
      y = ceil(u - 0.5);
    }
  } else {
    y = u;
  }

  return y;
}

/* Model step function for TID0 */
void trajectory_servo_control_step0(void) /* Sample time: [0.005s, 0.0s] */
{
  {                                    /* Sample time: [0.005s, 0.0s] */
    rate_monotonic_scheduler();
  }

  /* Update absolute time */
  /* The "clockTick0" counts the number of times the code of this task has
   * been executed. The absolute time is the multiplication of "clockTick0"
   * and "Timing.stepSize0". Size of "clockTick0" ensures timer will not
   * overflow during the application lifespan selected.
   */
  trajectory_servo_control_M->Timing.taskTime0 =
    ((time_T)(++trajectory_servo_control_M->Timing.clockTick0)) *
    trajectory_servo_control_M->Timing.stepSize0;
}
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

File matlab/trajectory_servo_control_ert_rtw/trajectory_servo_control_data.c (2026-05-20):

/*
 * File: trajectory_servo_control_data.c
 *
 * Code generated for Simulink model 'trajectory_servo_control'.
 *
 * Model version                  : 1.4
 * Simulink Coder version         : 24.1 (R2024a) 19-Nov-2023
 * C/C++ source code generated on : Mon May 18 10:21:15 2026
 *
 * Target selection: ert.tlc
 * Embedded hardware selection: ARM Compatible->ARM Cortex
 * Code generation objectives: Unspecified
 * Validation result: Not run
 */

#include "trajectory_servo_control.h"

/* Block parameters (default storage) */
P_trajectory_servo_control_T trajectory_servo_control_P = {
  /* Variable: pj1
   * Referenced by: '<S6>/Lookup'
   */
  { 60.24, 64.08, 49.34, 71.22, 129.1, 138.0, 150.3, 165.4 },

  /* Variable: pj2
   * Referenced by: '<S2>/Lookup'
   */
  { -18.68, -0.7368, -1.352, -1.29, -22.21, -9.108, -1.665, -0.8548 },

  /* Variable: pj3
   * Referenced by: '<S3>/Lookup'
   */
  { -90.0, -90.0, -90.0, -90.0, -69.96, -82.95, -89.44, -90.0 },

  /* Variable: pj4
   * Referenced by: '<S4>/Lookup'
   */
  { 180.0, 180.0, 180.0, 180.0, 169.0, 175.7, 179.7, 180.0 },

  /* Variable: pj5
   * Referenced by: '<S5>/Lookup'
   */
  { 101.6, 131.7, 86.55, 89.44, 135.0, 135.0, 135.0, 135.0 },

  /* Mask Parameter: RepeatingSequenceInterpolated1_
   * Referenced by: '<S3>/Lookup'
   */
  { 0.0, 1.0, 2.0, 3.0, 4.0, 5.0, 6.0, 7.0 },

  /* Mask Parameter: RepeatingSequenceInterpolated2_
   * Referenced by: '<S4>/Lookup'
   */
  { 0.0, 1.0, 2.0, 3.0, 4.0, 5.0, 6.0, 7.0 },

  /* Mask Parameter: RepeatingSequenceInterpolated3_
   * Referenced by: '<S5>/Lookup'
   */
  { 0.0, 1.0, 2.0, 3.0, 4.0, 5.0, 6.0, 7.0 },

  /* Mask Parameter: RepeatingSequenceInterpolated_T
   * Referenced by: '<S2>/Lookup'
   */
  { 0.0, 1.0, 2.0, 3.0, 4.0, 5.0, 6.0, 7.0 },

  /* Mask Parameter: RepeatingSequenceInterpolated4_
   * Referenced by: '<S6>/Lookup'
   */
  { 0.0, 1.0, 2.0, 3.0, 4.0, 5.0, 6.0, 7.0 },

  /* Mask Parameter: WrapToZero_Threshold
   * Referenced by: '<S12>/FixPt Switch'
   */
  700U,

  /* Mask Parameter: WrapToZero_Threshold_e
   * Referenced by: '<S15>/FixPt Switch'
   */
  700U,

  /* Mask Parameter: WrapToZero_Threshold_j
   * Referenced by: '<S18>/FixPt Switch'
   */
  700U,

  /* Mask Parameter: WrapToZero_Threshold_c
   * Referenced by: '<S9>/FixPt Switch'
   */
  700U,

  /* Mask Parameter: WrapToZero_Threshold_ch
   * Referenced by: '<S21>/FixPt Switch'
   */
  700U,

  /* Computed Parameter: SampleTimeMath_WtEt
   * Referenced by: '<S3>/Sample Time Math'
   */
  0.01,

  /* Expression: 85
   * Referenced by: '<Root>/Add Constant'
   */
  85.0,

  /* Computed Parameter: SampleTimeMath_WtEt_i
   * Referenced by: '<S4>/Sample Time Math'
   */
  0.01,

  /* Expression: -180
   * Referenced by: '<Root>/Add Constant1'
   */
  -180.0,

  /* Computed Parameter: SampleTimeMath_WtEt_c
   * Referenced by: '<S5>/Sample Time Math'
   */
  0.01,

  /* Expression: -42.3
   * Referenced by: '<Root>/Add Constant3'
   */
  -42.3,

  /* Computed Parameter: SampleTimeMath_WtEt_l
   * Referenced by: '<S2>/Sample Time Math'
   */
  0.01,

  /* Expression: 85
   * Referenced by: '<Root>/Add Constant4'
   */
  85.0,

  /* Expression: 41.8128505727844
   * Referenced by: '<Root>/Constant'
   */
  41.8128505727844,

  /* Computed Parameter: SampleTimeMath_WtEt_lo
   * Referenced by: '<S6>/Sample Time Math'
   */
  0.01,

  /* Computed Parameter: Constant_Value_h
   * Referenced by: '<S9>/Constant'
   */
  0U,

  /* Computed Parameter: Constant_Value_l
   * Referenced by: '<S12>/Constant'
   */
  0U,

  /* Computed Parameter: Constant_Value_e
   * Referenced by: '<S15>/Constant'
   */
  0U,

  /* Computed Parameter: Constant_Value_a
   * Referenced by: '<S18>/Constant'
   */
  0U,

  /* Computed Parameter: Constant_Value_n
   * Referenced by: '<S21>/Constant'
   */
  0U,

  /* Computed Parameter: Output_InitialCondition
   * Referenced by: '<S10>/Output'
   */
  0U,

  /* Computed Parameter: FixPtConstant_Value
   * Referenced by: '<S11>/FixPt Constant'
   */
  1U,

  /* Computed Parameter: Output_InitialCondition_g
   * Referenced by: '<S13>/Output'
   */
  0U,

  /* Computed Parameter: FixPtConstant_Value_m
   * Referenced by: '<S14>/FixPt Constant'
   */
  1U,

  /* Computed Parameter: Output_InitialCondition_l
   * Referenced by: '<S16>/Output'
   */
  0U,

  /* Computed Parameter: FixPtConstant_Value_a
   * Referenced by: '<S17>/FixPt Constant'
   */
  1U,

  /* Computed Parameter: Output_InitialCondition_p
   * Referenced by: '<S7>/Output'
   */
  0U,

  /* Computed Parameter: FixPtConstant_Value_c
   * Referenced by: '<S8>/FixPt Constant'
   */
  1U,

  /* Computed Parameter: Output_InitialCondition_b
   * Referenced by: '<S19>/Output'
   */
  0U,

  /* Computed Parameter: FixPtConstant_Value_b
   * Referenced by: '<S20>/FixPt Constant'
   */
  1U
};

/*
 * File trailer for generated code.
 *
 * [EOF]
 */

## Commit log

2026-05-18 Initial robotic arm full stack project structure
2026-05-18 Convert robot_arm from submodule to normal directory
    [Full_aseembly.SLDASM3.csv, arm.urdf.xacro, base_link.STL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]
2026-05-18 uplaoded esp32 codes
2026-05-19 atlab files
    [Arm 01_Default_sldprt.STEP, Internal_gear_Default_sldprt.STEP, Servo Bracket - long U.step_Default_sldprt.STEP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]
2026-05-20 Add README.md file for CAD/Solidworks
2026-05-20 Added STL files for 32 printing
    [Arm 01.STL, Gear_guide(x4).STL, Gripper Arm(x2).STL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]
2026-05-20 matlab re
    [Arm 01_Default_sldprt.STEP, Internal_gear_Default_sldprt.STEP, Servo Bracket - long U.step_Default_sldprt.STEP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]
2026-05-20 matlab simulink upload
    [Arm 01_Default_sldprt.STEP, Internal_gear_Default_sldprt.STEP, Servo Bracket - long U.step_Default_sldprt.STEP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]
